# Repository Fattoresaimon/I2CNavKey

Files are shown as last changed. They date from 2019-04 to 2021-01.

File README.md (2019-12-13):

# I2C NavKey
--------------------------------------------------------------------------------
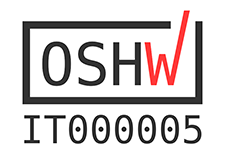
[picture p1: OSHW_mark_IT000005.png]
OSHW


## Introduction

The I2CNavKey is a small board that includes a 7 functions joypad.
The joypad has 4 directional keys plus a central button and a rotary ring. It is controllable with the I2C bus, and it's possible to configure 16 different I2C addresses.

The I2CNavKey has also 3 configurable GPIOs with the same footprint of RGB LED. This 3 GPIOs can be configured independently in 4 different way: input, output, PWM and analog input.

Since the I2CNavKey is a I2C slave, it has a series of 8 bit registers where it's possible to configure different parameters,it's also possible to detect when the buttons are pressed or when the ring is rotated.
It also has an open-drain output pin used as interrupt output. This pin is used to notify to the master when some event happens in the I2CNavKey, the source of interrupt can be customized.

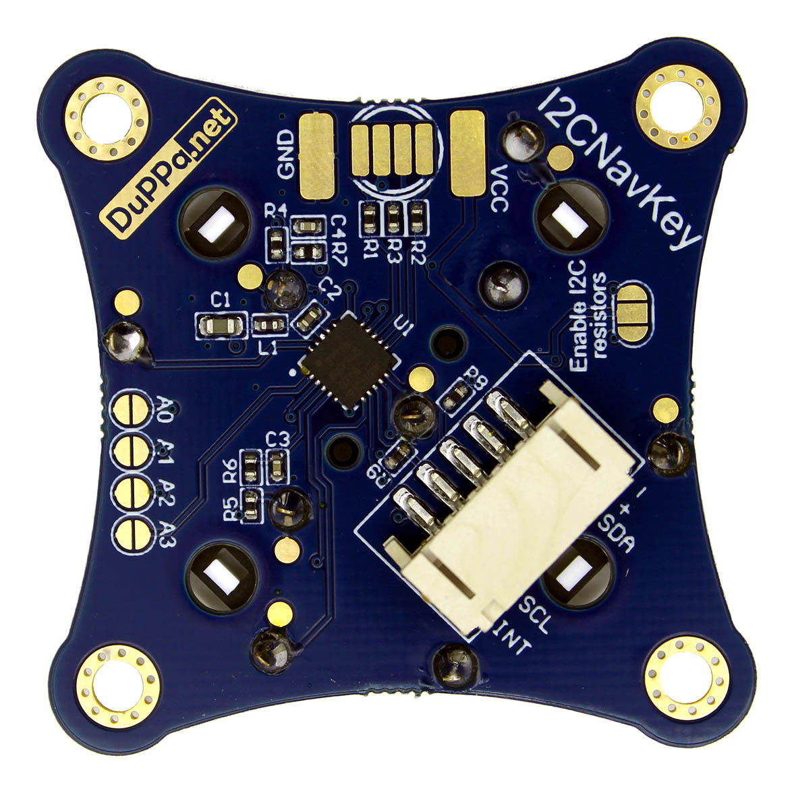
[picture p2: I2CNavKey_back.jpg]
I2CNavKey back side


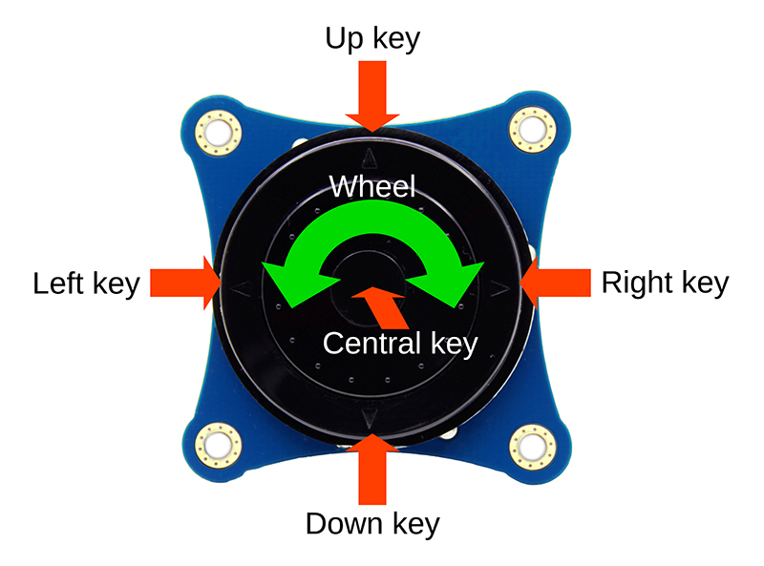
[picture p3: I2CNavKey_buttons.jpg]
I2CNavKey 7 functions


## Where you can get this board?

This project is avaiable on our [Tindie store!](https://www.tindie.com/products/16624/)

## Repository Structure
* [Arduino Library:](https://github.com/Fattoresaimon/ArduinoDuPPaLib) Repository where you can find the Arduino IDE library for the DuPPa boards
* [Raspberry Library:](/Python%20Raspberry%20Library) Ready to use library in Python for the Raspberry board with example.
* [Firmware:](/Firmware) Project folder of Microchip MPLAB X contain the code running inside of the PIC16F18345
* [Hardware:](/Hardware) Folder containing the production file, schematic, STEP file
* [Datasheet I2C NavKey:](I2CNavKey_v1.4.pdf) Datasheet of the board with the description of the registers and some useful information.

## Licensing

Hardware and firmware are licensed under GPL-3 license

Documentation is licensed under a Creative Commons BY-SA 4.0 international license

**If you want to donate for my work, i would really appreciate it. You can donate here with this link. Thank you!**



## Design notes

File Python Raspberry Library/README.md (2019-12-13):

# I2C NavKey Python library 
--------------------------------------------------------------------------------

## Introduction

Here you can find the library and some examples for Raspberry Pi.
For more details of the functionality of the board please read the [Datasheet](../I2CNavKey_v1.4.pdf) 

## Installation

The installation is very simple:

* Download the file [**i2cNavKeyLib.py** ](Source/i2cNavKeyLib.py) 
* Put the file in the folder where you have the source files.
* Import the library in your source files
``` python
import i2cNavKeyLib
```

## Initialization

The library makes available the class **i2cNavKeyLib**
For initialize the library you have to declare an instance of the class **i2cNavKeyLib** for each navkeys.
In the instance you have to declare the I2C address of the board
For example:

``` python
import smbus2
import i2cNavKeyLib

bus = smbus2.SMBus(1)
navkey = i2cNavKeyLib.i2cNavKeyLib(bus, 0x12)
```
In this example the I2C address is 0x12: jumpers A1 is soldered

## Callback Configuration

This library support the callback functionality.
There is the possibility to link a function to a specific interrupt of the I2C Encoder V2, in this way the function is automatically called when the I2C Encoder V2 generates an interrupts.

A callback function must be declared as the following:

```python
def NAME_OF_THE_FUNCTION():
```
There are 26 possible events:

| Event | Description |
|:---:|:---|
| onArrowsPush | One of the 4 direction keys is pressed |
| onArrowsRelese	| One of the 4 direction keys is released |
| onUpPush | Arrow up is pressed |
| onUpRelease | Arrow up is released |
| onDownPush | Arrow down is pressed |
| onDownRelease | Arrow down is released |
| onRightPush | Arrow right is pressed |
| onRightRelease | Arrow right is released |
| onLeftPush | Arrow left is pressed |
| onLeftRelease | Arrow left is released |
| onCentralPush | central button is pressed |
| onCentralRelease | central button is released |
| onCentralDoublePush | central button is double pushed |
| onIncrement | The counter value is incremented |
| onDecrement | The counter value is decremented |
| onChange | The counter value is incremented or decremented |
| onMax | The counter value reach the maximum threshold |
| onMin | The counter value reach the minimum threshold |
| onMinMax | The counter value reach the maximum or minimum threshold |
| onGP1Rise | GP1 configured as input, rising edge |
| onGP1Fall | GP1 configured as input, falling edge |
| onGP2Rise | GP2 configured as input, rising edge  |
| onGP2Fall | GP2 configured as input, falling edge  |
| onGP3Rise | GP3 configured as input, rising edge  |
| onGP3Fall | GP3 configured as input, falling edge  |
| onFadeProcess | Fade process terminated |

#### Examples:

```python
navkey = i2cNavKeyLib.i2cNavKeyLib(bus, 0x12)

...

 # Simple callback that ist's called when the UP button is pressed and blink the LED on GP1 #
def Up_Button():
    navkey.writeGP1(100)
    print ('Button Up Pushed!')
    navkey.writeGP1(0)

 # Simple callback that ist's called when the Down button is pressed and blink the LED on GP2 # 
def Down_Button():
    navkey.writeGP2(100)
    print ('Button Down Pushed!')
    navkey.writeGP2(0)
...

navkey.onUpPush = Up_Button # Attach the event of UP button to the callback function#
navkey.onDownPush = Down_Button # Attach the event of Down button to the callback function#

}

```

If you need to remove the link with a callback, you just need to define:
```python
navkey.onUpPush = None
```

## Methods

### Initialization
#### begin(conf)
This is used for initialize the I2CNavKey by writing the configuration register.
The parameters can be concatenate in OR mode.
Possible parameters are the following:

| Parameter | Description |
|:---:|:--- |
| INT_DATA | The Threshold, counter step and counter value are used with integer numbers |
| FLOAT_DATA | The Threshold, counter step and counter value are used with floating numbers |
| | |
| WRAP_ENABLE | Wrap enable. When the counter value reaches the CMAX+1, restart to the CMIN and vice versa |
| WRAP_DISABLE | Wrap disable. When the counter value reaches the CMAX or CMIN, the counter stops to increasing or decreasing |
| | |
| DIRE_LEFT | Rotate left side to increase the value counter |
| DIRE_RIGHT | Rotate right side to increase the value counter |
| | |
| IPUP_DISABLE | Disable the internall pull-up on the INT pin |
| IPUP_ENABLE | Enable the internall pull-up on the INT pin |
| | |
| CLK_STRECH_ENABLE | Enable the I2C clock stretch  |
| CLK_STRECH_DISABLE | Disable the I2C clock stretch  |
| | |
| EEPROM_BANK1 | Select the first EEPROM bank |
| EEPROM_BANK2 | Select the second EEPROM bank |
| | |
| RESET | Reset the board |

###### Examples:

```python
navkey.begin(i2cNavKeyLib.INT_DATA | i2cNavKeyLib.WRAP_ENABLE | i2cNavKeyLib.DIRE_RIGHT | i2cNavKeyLib.IPUP_ENABLE)
```

###  reset()
Reset of the board. 
In this command there is 8ms delay in order to make the board correctly restart.

### Configuration

#### GPx pins configuration

This 3 function are used for configure the GP pins. The parameter are the same for all of the 3 GP pins.
The interrupt configuration are used only when the pin is configured as digital input.

##### writeGP1conf(gp1)
##### writeGP2conf(gp2)
##### writeGP3conf(gp3)

| Parameter | Description |
|:---:|:---:|
|GP_PWM| Set the GP pin as PWM output|
|GP_OUT| Set the GP pin as digital output|
|GP_AN| Set the GP pin as analog input|
|GP_IN| Set the GP pin as digital input output|
|||
|GP_PULL_EN| Enable the internal pull-up of the pin|
|GP_PULL_DI| Disable the internal pull-up of the pin|
|||
|GP_INT_DI| Disable the pin interrupt|
|GP_INT_PE| Enable the interrupt at the positive edge|
|GP_INT_NE|  Enable the interrupt at the negative edge|
|GP_INT_BE|  Enable the interrupt at the positive and negative edge|

###### Examples:

```python
navkey.writeGP1conf(i2cNavKeyLib.GP_AN | i2cNavKeyLib.GP_PULL_DI | i2cNavKeyLib.GP_INT_DI)  # Configure the GP1 as analog input with the pull-up and the interrupt disable #
```

##### writeInterruptConfig(interrupt)

This method is used for enable or disable the interrupt source selectively. When an interrupt event occurs, the INT pin goes low and the event is stored in the status register.

| Parameter | Description |
|:---:|:---|
| UPR | Arrow up is released |
| UPP | Arrow up is pressed |
| DNR | Arrow down is released |
| DNP | Arrow down is pressed |
| RTR | Arrow right is released |
| RTP | Arrow right is pressed |
| LTR | Arrow left is released |
| LTP | Arrow left is pressed |
| CTRR  | Central button is released |
| CTRP  | Central button is pressed |
| CTRDP | Central button is double pushed |
| RINC  | Encoder is rotated in the increment direction  |
| RDEC  | Encoder is rotated in the decrement direction  |
| RMAX  | Maximum threshold is reached  |
| RMIN  | Minimum threshold is reached  |
| INT_2  | An event on the interrupt 2 register occurs |

###  void autoconfigInterrupt(void)

This method auto configures the **INTCONF** register according to the attached callback.
**For the proper use, must be called after the definition of the last event property.**

```python

navkey.onUpPush = Up_Button
navkey.onDownPush = Down_Button
navkey.onLeftPush = Left_Button
navkey.onRightPush = Right_Button
navkey.onCentralPush = Push_Button
navkey.onCentralDoublePush = DoublePush_Button
navkey.onChange = EncoderChange
navkey.onMax = EncoderMax
navkey.onMin = EncoderMin
  # Enable the I2C NavKey interrupts according to the previous attached callback #
navkey.autoconfigInterrupt()

```

##### writeDoublePushPeriod(dperiod)

This method is used for setting the window period **DPPERIOD** of the double push of the central button. When the value is 0, the double push option is disabled.
The I2C NavKey will multiplies this value by 10 (value x10).
###### Examples:

```python
navkey.writeDoublePushPeriod(50)  # Set a period for the double push of 500ms # 
```

##### writeFadeGP(fade)

This method is used for setting the fade speed **FADEGP** of the GP pins. It the value is 0 the fade option is disabled.

###### Examples:

```python
  navkey.writeFadeGP(5)  #GP Fade enabled with 5ms step 
```

### writeGammaGP1(gamma)
### writeGammaGP2(gamma)
### writeGammaGP3(gamma)

This method is used to set a gamma correction in case the GP pin is set to PWM

| Parameter | Description |
|:---:|:---|
| GAMMA_OFF | Gamma correction is OFF |
| GAMMA_1 | Gamma is 1, in this case the PWM is linear |
| GAMMA_1_8 | Gamma is 1.8 |
| GAMMA_2 | Gamma is 2 |
| GAMMA_2_2 | Gamma is 2.2 |
| GAMMA_2_4 | Gamma is 2.4 |
| GAMMA_2_6 | Gamma is 2.6 |
| GAMMA_2_8 | Gamma is 2.8 |

#### Examples:

```python
  navkey.writeGammaGP1(i2cNavKeyLib.GAMMA_2)
  navkey.writeGammaGP2(i2cNavKeyLib.GAMMA_2)
  navkey.writeGammaGP3(i2cNavKeyLib.GAMMA_2)
```

### Status

##### updateStatus()
Read the I2CNavKey status register **ISTATUS**. In case of events the attached callback is called.
Return value is **true** in case of some event, otherwise is **false**
In case an event of the SSTATUS  register, the SSTATUS is automatically be read.

###### Examples:

```python
  if navkey.updateStatus() == True :
  # Something happens
  
```

##### readStatus(status)

Must be called after **updateStatus()**, this method is used for checking if some event occurs on the **ISTATUS** register.
Return value is **true** in case of the event occurred, otherwise is **false**
Possible parameters are:

| Parameter | Description |
|:---:|:---|
| UPR | Arrow up is released |
| UPP | Arrow up is pressed |
| DNR | Arrow down is released |
| DNP | Arrow down is pressed |
| RTR | Arrow right is released |
| RTP | Arrow right is pressed |
| LTR | Arrow left is released |
| LTP | Arrow left is pressed |
| CTRR  | Central button is released |
| CTRP  | Central button is pressed |
| CTRDP | Central button is double pushed |
| RINC  | Encoder is rotated in the increment direction  |
| RDEC  | Encoder is rotated in the decrement direction  |
| RMAX  | Maximum threshold is reached  |
| RMIN  | Minimum threshold is reached  |
| INT_2  | An event on the interrupt 2 register occurs |

###### Example:
```python

 if  navkey.updateStatus() == True :
      if  navkey.readStatus(UPR) == True :
      	print ('Button Up Pushed!') 
      
      if  navkey.readStatus(DNR) == True :
      	print ('Button Down Pushed!') 

      if  navkey.readStatus(RTR) == True :
      	print ('Button Left Pushed!') 

      if  navkey.readStatus(LTR) == True :
      	print ('Button Right Pushed!')  

      if  navkey.readStatus(PUSHP) == True :
      	print ('Encoder pushed!')  
        
	  if  navkey.readStatus(PUSHR) == True :
      	print ('Encoder released!')   

      if  navkey.readStatus(PUSHD) == True :
      	print ('Encoder double pushed!')

```

##### readStatus()

Return the status of the register **ESTATUS**

##### readInt2(status)
Must be called after **updateStatus()**, this method is used for check if some event occurred one the secondary interrupt status **SSTATUS** register.
Return value is **true** in case of the event occurred, otherwise is **false**
Possible parameter are:

| Parameter | Description |
|:---:|:---:|
| GP1_POS  | Positive edge on the GP1 pin |
| GP1_NEG  | Negative edge on the GP1 pin |
| GP2_POS  | Positive edge on the GP2 pin |
| GP2_NEG  |Negative edge on the GP2 pin |
| GP3_POS  | Positive edge on the GP3 pin|
| GP3_NEG  |Negative edge on the GP3 pin |
| FADE_INT |Fade process finished |

###### Example:
```python
 if  navkey.updateStatus() == True :
      if  navkey.readInt2(GP1_POS)
        print("GP1 positive edge")
      
      if navkey.readInt2(GP1_NEG) == True :
        print ('GP1 negative edge ')

      if navkey.readInt2(GP2_POS)  == True :
          print('GP2 positive edge')

      if  navkey.readInt2(GP2_NEG) == True :
        print('GP2 negative edge ')

      if  navkey.readInt2(GP3_POS) == True :
        print('GP3 positive edge')

      if  navkey.readInt2(GP3_NEG) == True :
        print('GP3 negative edge ')

      if  navkey.readInt2(FADE_INT) == True :
        print('Fade process finished') 
      
```

##### readInt2Raw()

Return the status of the register **SSTATUS**

##### readFadeStatus(status)

When this function is called, it performs a I2C reading.
This function return **true** when the fade running, otherwise return **false**

| Parameter | Description |
|:---:|:---:|
| FADE_GP1  | Fade process status of the GP1 |
| FADE_GP2  | Fade process status of the GP2 |
| FADE_GP3  | Fade process status of the GP3 |

##### readFadeStatusRaw()

Return the value of the register **FSTATUS**.

### Reading methods
In this section are listed all the reading method available

##### readCounter32()
Return the counter value in the format **32bit int**, by reading all the 4 bytes of the counter value registers.

##### readCounter16()
Return the counter value in the format **16bit int**, by reading the 2 LSB  of the counter value registers.
Useful when the counter register is between the values -32768 to 32767.

##### readCounter8()
Return the counter value in the format **8bit int**, by reading the LSB byte of the counter value register.
Useful when the counter register is between the values -128 to 127

##### readCounterFloat()
Return the counter value in the format **float**, by reading all the 4 bytes of the counter value registers.
For using this function you have to configure the board with the parameter **FLOAT_DATA**.

##### readMax()
Return the maximum threshold in format **32bit int**, bye reading all the 4 bytes of the counter Max.

##### readMaxFloat()
Return the maximum threshold in format **float**, bye reading all the 4 bytes of the counter Max.

##### readMin()
Return the minimum threshold in format **32bit int**, by reading all the 4 byte of the counter Min.

##### readMinFloat()
Return the minimum  threshold in format **float**, bye reading all the 4 bytes of the counter Min.

##### readStep()
Return the minimum threshold in format **32bit int**, by reading all the 4 bytes of the ISTEP registers.

##### readStepFloat()
Return the step value in format **float**, by reading all the 4 bytes of the ISTEP registers .

##### readGP1()
Return the value of the GP1REG register. 
If the **GP1** is configured as input, it's possible to read the logic status of the pin: *1* when the pin is high, otherwise *0*.
If the **GP1** is configured as analog, it's possible to read the 8bit of the ADC.

##### readGP2()
Return the value of the GP2REG register. 
If the **GP2** is configured as input, it's possible to read the logic status of the pin: *1* when the pin is high, otherwise *0*.
If the **GP2** is configured as analog, it's possible to read the 8bit of the ADC.

##### readGP3()
Return the value of the GP3REG register. 
If the **GP3** is configured as input, it's possible to read the logic status of the pin: *1* when the pin is high, otherwise *0*.
If the **GP3** is configured as analog, it's possible to read the 8bit of the ADC. 

##### readDoublePushPeriod()
Return the value of the DPPERIOD register. 

##### readFadeGP()
Return the value of the FADEGP register. 

##### readIDCode()
Return the ID code of the I2C NavKey, that is 0x5B

##### readVersion()
Return the version of the board. 

##### readEEPROM(add)
Return the value of the EEPROM register. 
This function automatically manage the setting of the first and second memory bank.

### Writing methods

#####  writeCounter(value)
Write the counter value register with a  **32bit int** number. All of the 4 bytes are wrote.

#####  writeCounterFloat(value)
Write the counter value register with a  **float** number. All of the 4 bytes are wrote.

#####  writeMax(max)
Write the Max register with a  **32bit int** number. All of the 4 bytes are wrote.

#####  writeMax(max)
Write the Max register with a  **float** number. All of the 4 bytes are wrote.

#####  writeMin(min)
Write the Min register with a **32bit int** number. All of the 4 bytes are wrote.

#####  writeMinFloat(min)
Write the Min register with a **float** number. All of the 4 bytes are wrote.

#####  writeStep(step)
Write the increment step  with a  **32bit int** number. All of the 4 bytes are wrote.

#####  writeStepFloat(step)
Write the increment step with a  **float** number. All of the 4 bytes are wrote.

##### writeGP1(gp1)
Write the GP1REG register.
If the GP1 is configure as PWM with this method it's possible to write the PWM value.
If the GP1 is configure as output with this method it's possible to write the logic status: 1 for high, while 0 for low.

##### writeGP2(gp2)
Write the GP2REG register.
If the GP2 is configure as PWM with this method it's possible to write the PWM value.
If the GP2 is configure as output with this method it's possible to write the logic status: 1 for high, while 0 for low.

##### writeGP3(gp3)
Write the GP2REG register.
If the GP2 is configure as PWM with this method it's possible to write the PWM value.
If the GP2 is configure as output with this method it's possible to write the logic status: 1 for high, while 0 for low.

##### writeDoublePushPeriod(dperiod)
Write the DPPERIOD register.

##### writeFadeGP(fade)
Write the FADEGP register.

##### writeGammaGP1(gamma)
Configure the gamma correction for the GP1 pin

##### writeGammaGP2(gamma)
Configure the gamma correction for the GP2 pin

##### writeGammaGP3(gamma)
Configure the gamma correction for the GP3 pin

##### writeEEPROM(add, data)
Write the EEPROM memory.
The input parameter *add* is the address. This method automatically change the first or the second bank.
The input parameter *data* is the data that will be written.

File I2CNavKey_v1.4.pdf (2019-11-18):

www.duppa.net

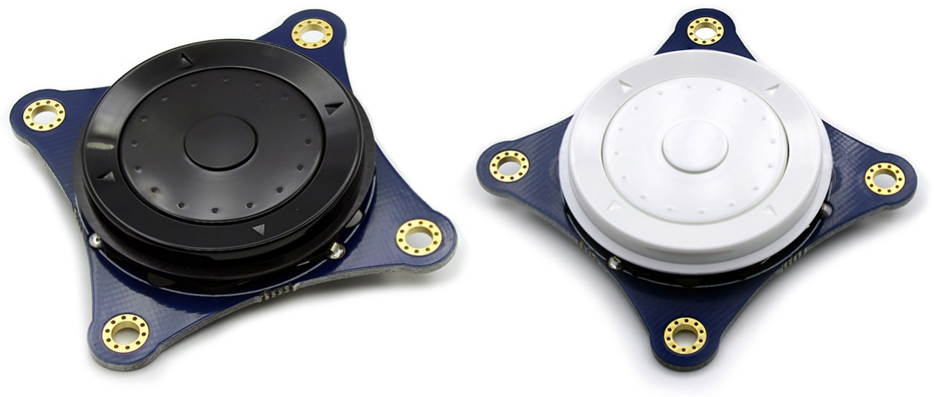
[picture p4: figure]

# I2CNavKey

## HW V1.2

November 18, 2019

Document written in LATEX

www.duppa.net | I2CNavKey

# Revision History

Revision | Date | Author(s) | Description
1.4 | 14.11.19 | Simone | Document update to the HW V1.2
1.3 | 01.08.19 | Simone | Small changes on this document layout
1.2 | 09.07.19 | Simone | Fixed the numbering of the gamma type
1.1 | 26.05.19 | Simone | Added the pull-up resistors jumpers and new photos
1.0 | 08.04.19 | Simone | First version

# Contents

1 Device Overview | 4
2 Registers | 14
3 Reference | 29
4 Issues | 30
5 Changelog | 31

6 Schematic | 32

# 1. Device Overview

The I2CNavKey is a small board that includes a 7 functions joypad.
The joypad has 4 directional keys plus a central button and a rotary ring. It is controllable with the I²C bus, and it’s possible to configure 16 different I²C addresses.

The I2CNavKey has also 3 configurable GPIOs with the same footprint of RGB LED. This 3 GPIOs can be configured independently in 4 different way: input, output, PWM and analog input.

Since the I2CNavKey is a I²C slave, it has a series of 8 bit registers where it’s possible to configure different parameters, it’s also possible to detect when the buttons are pressed or when the ring is rotated.
It also has an open-drain output pin used as interrupt output. This pin is used to notify to the master when some event happens in the I2CNavKey, the source of interrupt can be customized.

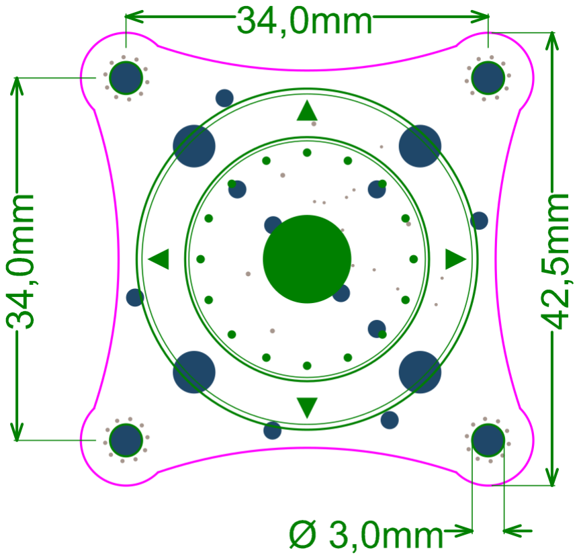
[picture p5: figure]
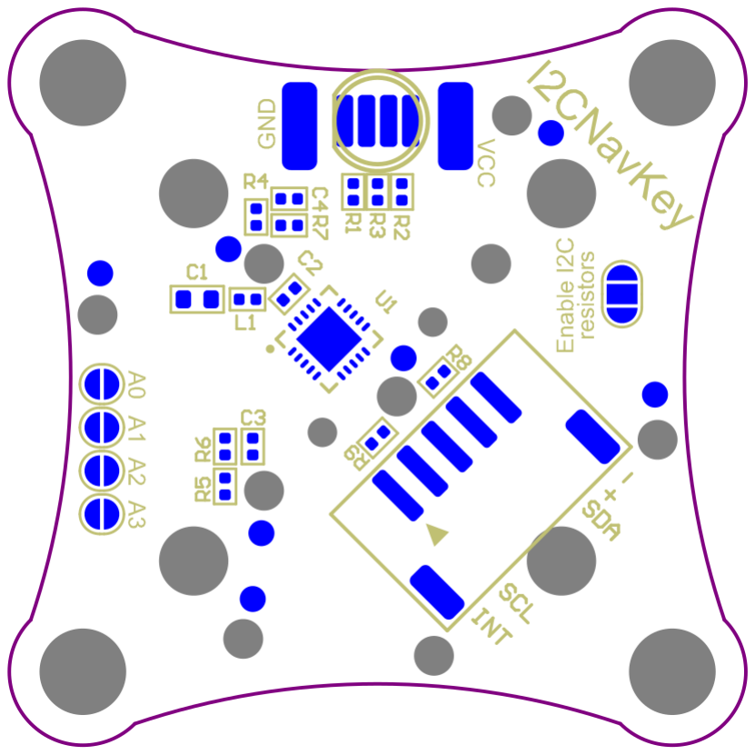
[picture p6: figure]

Figure 1.1: Dimension | Figure 1.2: Bottom view of the board

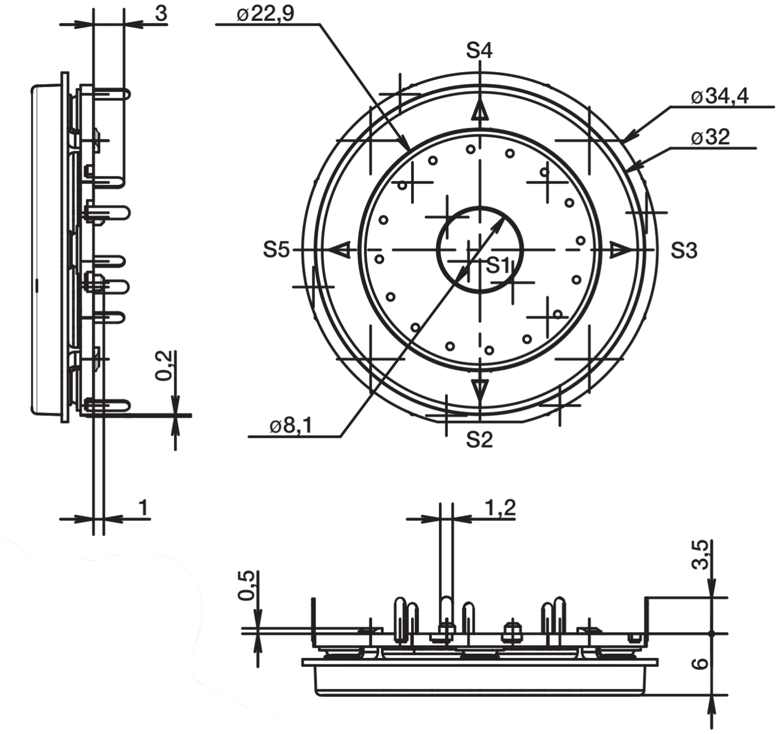
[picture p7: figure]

Figure 1.3: Dimension of the joypad: TSWB-3N-CB222 LFS from C&K

## 1.1 Electrical characteristics

Parameter | Symbol | Min | Max
Supply voltage | VDD | 3V | 5V
2C input-low level I | VIL | 0 | 0.3 * VDD
2C input-high level I | VIH | 0.8 * VDD | VDD
2C clock input frequency I | fSCL | | 400kHz
Supply current (LEDs off) | IDD | | 1.8mA
Interrupt pull-up resistor | RINT | 15kΩ | 120kΩ

## 1.2 Connection

Figure 1.2 shows the pin-out of the I2CNavKey.

Pin | I/O Type | Function
GND | Power | Ground reference for logic
Vcc | Power | Positive supply for logic
SDA | I/O | 2C data I
SCL | I | 2C clock I
INT | OD | Open-drain interrupt output

There is a 5 pin connector used to connect I2CNavKey to the master. In the HW v1.1 there is a vertical JST XH, while in the new version V1.2 there is a smaller connector JST PH mounted horizontally.

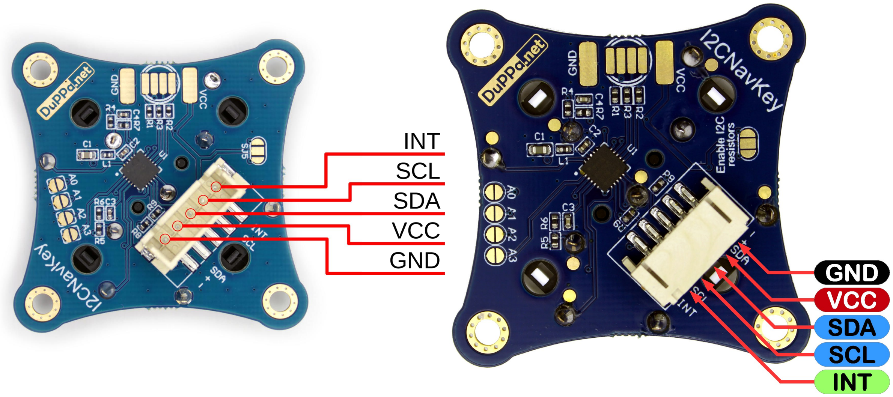
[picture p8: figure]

Figure 1.4: Pinout of the board in the previous
version HW V1.1

Figure 1.5: Pinout of the board in the HW V1.2

In order to avoid I²C address conflict with other devices on the bus, the address of each device must be different. In the section 1.3, it is described how to set the address.

## 1.3 I

## 2C interface

The I2CNavKey is a I²C slave, it’s possible to the set 16 different addresses. All of the 7-bit address can be customized by soldering the jumpers A0 - A3 on the bottom of the board. When the jumper is open, it means a logic 0. if jumper is shorted it means a logic 1.

I

2C address

7 | 6 | 5 | 4 | 3 | 2 | 1 | 0
0 | 0 | 1 | A3 | A2 | A1 | A0 | R/W

For example in the figure 1.7 the jumper A0 and A2 are shorted and the 7-bit I²C address is 21 in decimal or 0x15 in hexadecimal or 0b00010101 in binary.

The I2CNavKey has I²C pull-up resistors, by default they are not enabled. In order to enable the resistor the jumper SJ5 must be soldered.
This must be done in case that the master doesn’t have these resistors and must be enabled only one I2CNavKey in a chain. A typical value of this resistors are 4.7kΩ.
In the figure 1.7 is showed how to short the jumper SJ5.

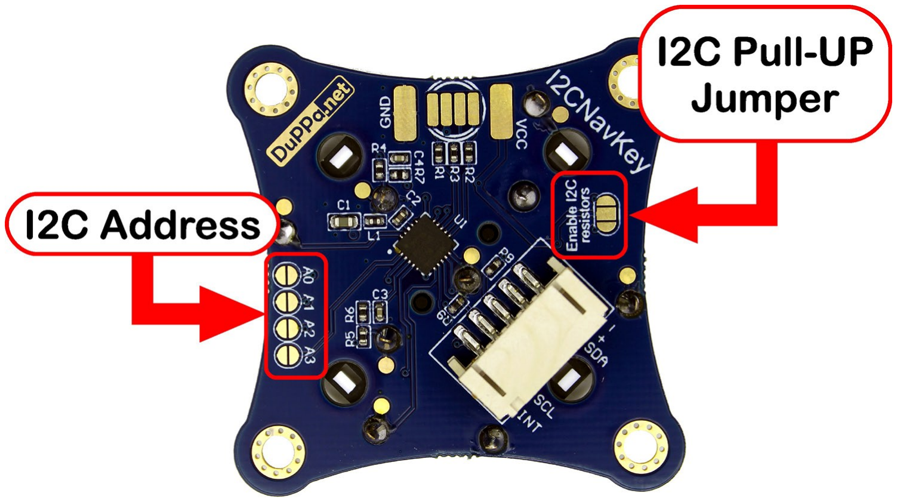
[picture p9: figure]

Figure 1.6: Jumper location of the pull-up resistor and of the address

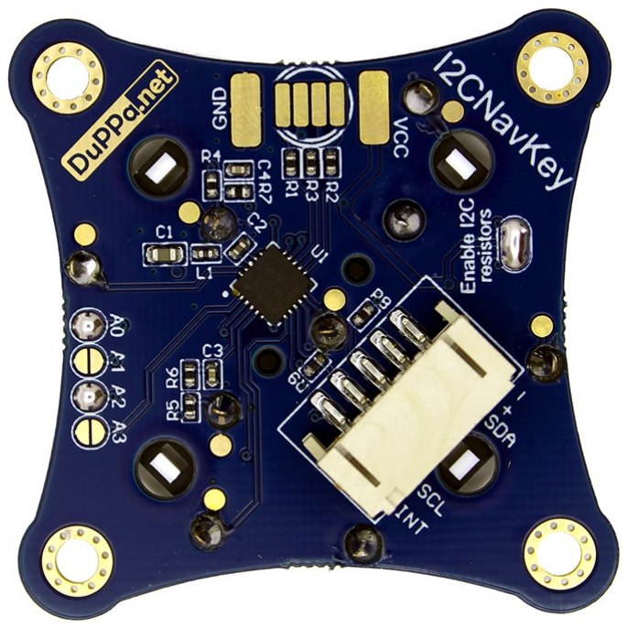
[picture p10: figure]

Figure 1.7: Example of jumper soldered: A0 and A2 shorted and also the SJ5 is shorted enabling the pull-up resistors

## 1.4 Joypad

On the I2CNavKey, there is a joypad with 7 functions:

- 4 directional buttons: up, down, left and right
- 1 central button
- Central wheel that can be rotated left and right, and it has 12 pulses per rotation.

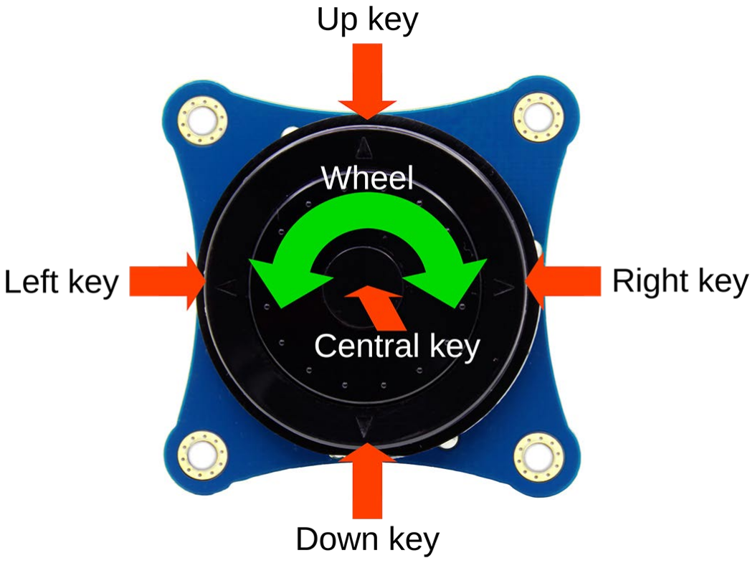
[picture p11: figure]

Figure 1.8: 7 function of the joypad

### 1.4.1 Buttons

When a button is pressed, the specific bit is set in the register ISTATUS. Every button has 2 specific bits because it’s possible to detect when the button is pressed and when is released.
The central button has also the possibility to read a fast double push by setting a window time in the register DPPERIOD. When a double push is made inside of the DPPERIOD window, the bit SCTRDP is set and it is possible to read in the ISTATUS register.
If the DPPERIOD is 0, the double push function is disabled.

### 1.4.2 Encoder

For reading the rotary encoder movement, there are 4 of 32bit registers: CVAL, CMAX, CMIN and ISTEP. All of these 4 registers can be configured to work as 32bit int or as IEEE 754 floating number, this format can be set in the GCONF register.
The counter limits are the following:
- 32bit INT: from −2147483648 to +2147483647
- IEEE 754 float: from −126.0 to +127.0

In case of 32bit int, it is not necessary to read all the 4 bytes, you can read only the first 8 bit or the first 16 bit. For example, if you want to count between 0 and 10, you can read only the first byte of the CVAL register. In this way, you can save I2C transactions.
Every time the encoder moves one step, the value of the CVAL register is increased or decreased of the value of ISTEP. The direction of the rotation decides if ISTEP is added or subtracted from CVAL.
CMAX and CMIN are used for setting a minimum and maximum thresholds of CVAL. In the GCONF register, there is WRAPE bit. This bit is used to enable or disable a wrap functionality of CVAL when it exceeds from the thresholds.
For example, if i configure the I2CNavKey as following:
- CVAL= 0
- CMAX = 5
- CMIN = -5
- ISTEP= 1

I will have CVAL is incremented of 1 at each rotation step of the encoder. The maximum value that CVAL can reach will be 5 while the minimum is -5. In the figure 1.9 shows the value of CVAL.

As showed in the figure 1.10, when WRAPE is set to 1 when CVAL reaches the value of 5, at the next increment CVAL it will be wrapped to -5.
Every time when the encoder is rotated one step and when CVAL reaches the thresholds, an interrupt is generated and it is possible to read in the register ISTATUS.

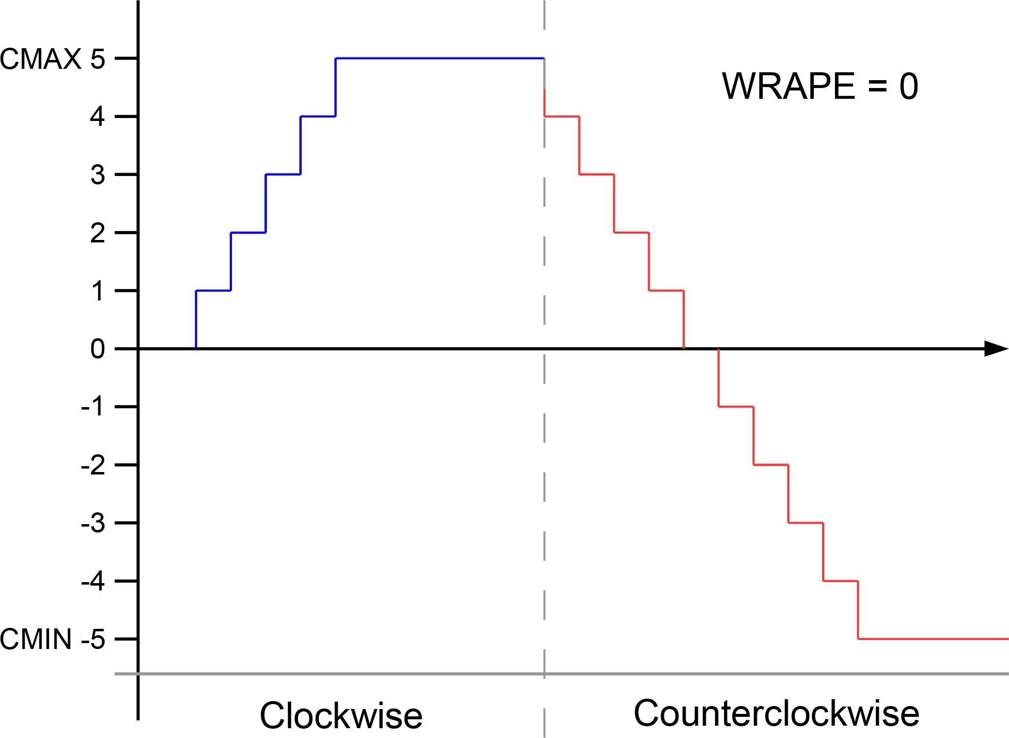
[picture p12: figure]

Figure 1.9: Blue and red lines are the CVAL values when the encoder is rotated and the WRAPE is disabled

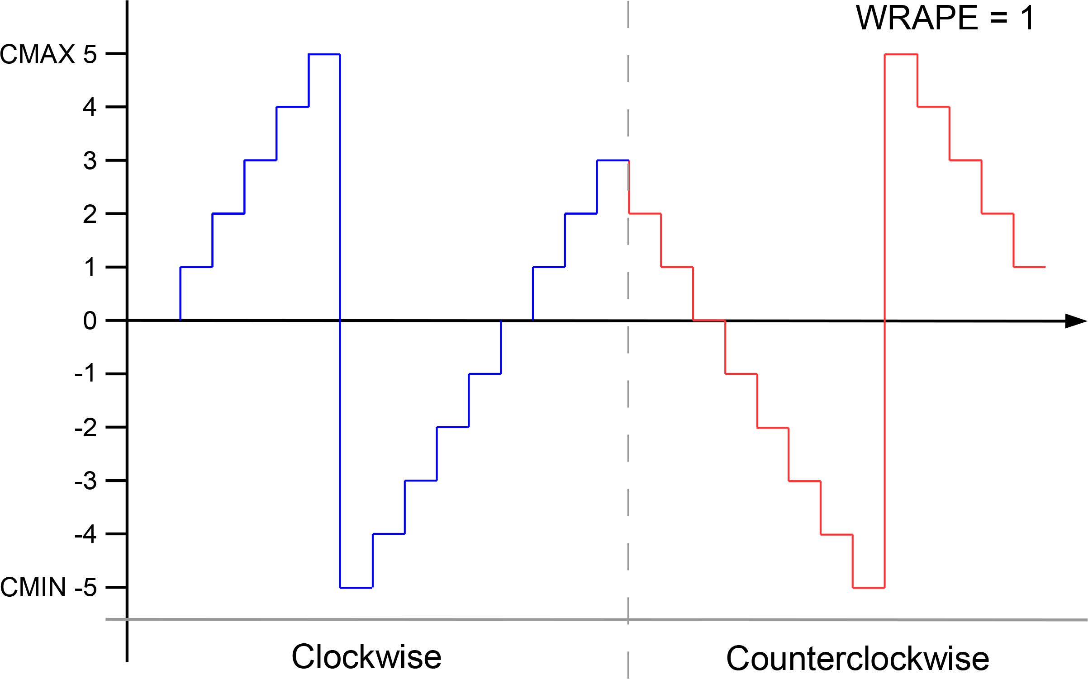
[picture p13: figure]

Figure 1.10: Blue and red line are the CVAL values when the encoder is rotate and the WRAPE is enabled

## 1.5 GP pins

There are 3 configurable GP pins, they are called GP1, GP2 and GP3. They have the same footprint of an 5mm RGB led. In figure 1.11, it is shown the position. Each pin can be configured to be:

- PWM: The pins is configured to be a PWM output.
- Analog input: The pins is configured to be an input of the internal ADC.
- GPIO output: The pins is configured to be a digital output.
- GPIO Input: The pin is configured to be a digital input.

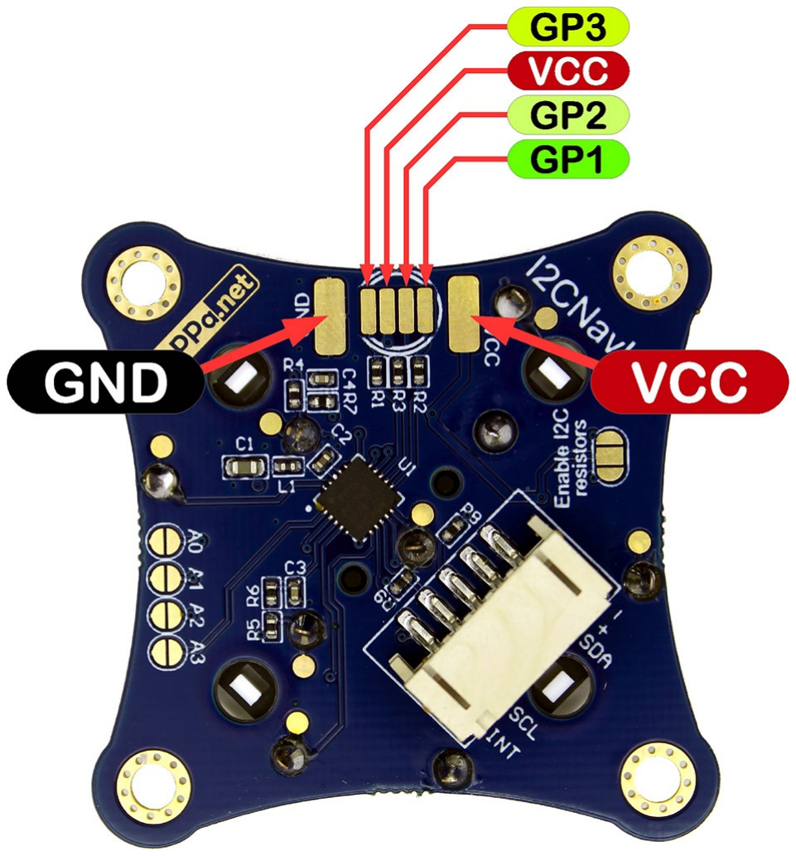
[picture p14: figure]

Figure 1.11: GP pins pinout

### 1.5.1 PWM mode

A GP pins can be configured in PWM mode by configuring the GPxMODE 1
to 0x00. The default configuration of the GP pins at the start up is PWM. Once the GP pin is configure in PWM mode, it is possible to set the PWM value by writing the corresponding GPxREG.
The PWM is resolution 10bit with a frequency of 31.25kHz, but the user can not access to the full resolution. It is possible to set a PWM value between 0% to 100% by writing 0 to 100 to the GPxREG.
The PWM is inverted, this means that when the PWM is 0% the GP pin voltage is VCC while when it is 100% the GP pin is GND.
In this way it is possible to connect a common anode RGB LED and have the LED off when the PWM is 0 and full on when the PWM is 100.
To each PWM outputs it is possible to configure a specific gamma correction by writing the register GAMMAGPx. There are 7 type of gamma correction:

✥ Gamma 1 (linear)

✥ Gamma 1.8

✥ Gamma 2.0

✥ Gamma 2.2

✥ Gamma 2.4

✥ Gamma 2.6

✥ Gamma 2.8

In the figure 1.12 is showed the relationship between the PWM at the full resolution and the PWM settable from the user.

1
In a register name the x correspond to 1, 2 or 3

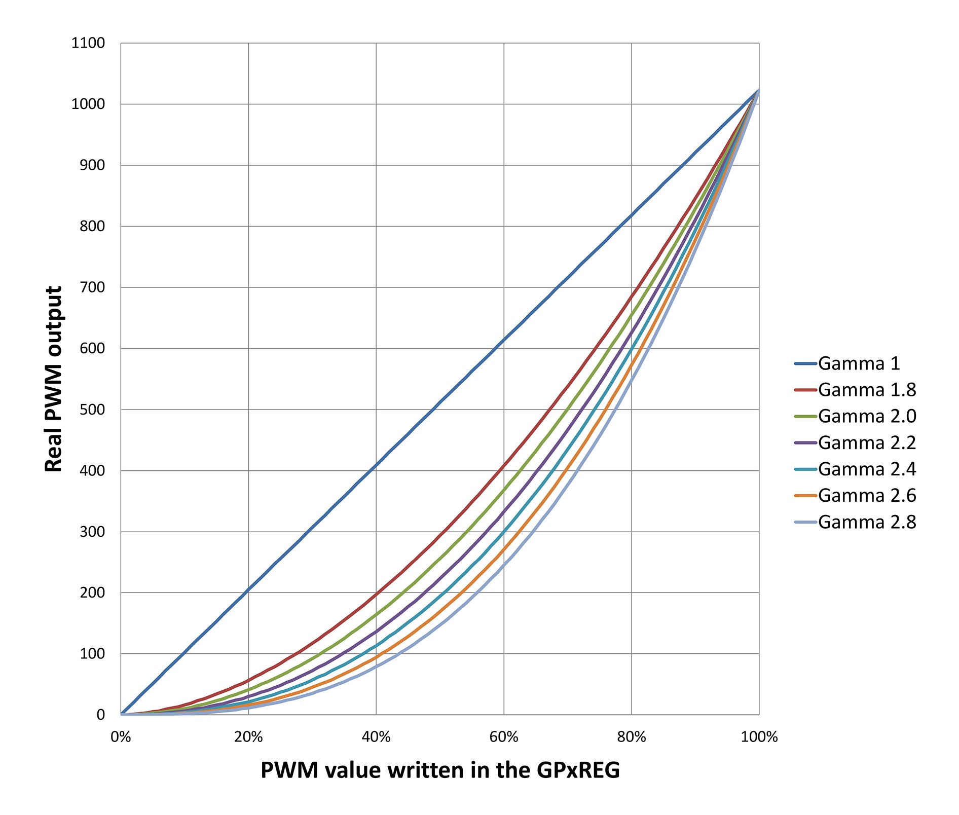
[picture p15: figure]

Figure 1.12: Possible gamma option

Fade function

The I2CNavKey has an auto fading features.
There is the register FADEGP, the value you write inside these registers is the step speed of the fading ramp, and it’s in ms. The fading will follow the selected gamma correction. If the value is 0, the fade feature is disabled. It means that when the new value of PWM is written, it is immediately updated to the output.
The fading process starts when a PWM value is written. Fading process is complete according to the PWM value you have set. When the internal fade PWM value is the same of the PWM value (it means that when fading is complete), an interrupt will be generated. Let’s make an example:

At the startup, i write as:

- GP1REG = 0
- GP2REG = 0
- GP3REG = 0
- FADEGP = 1

In above case, the LEDs of the encoder are off and the fade has 1ms step size.
Now i write as: GP1REG=100.
This moment, the ramp of the GP1REG starts and reaches the value 0x100 in 100ms. (the other LEDs remain OFF) When the ramp reaches 100, i get an interrupt from the INT pin.
After this, i write as: GP1REG=0x00. At this point, the fade ramp starts again and it will turn off the LED in 100ms, and an interrupt will be generated at the end.
The figure 1.13 is showing an example of the fade output when a PWM value is written in different moments, as well as when the interrupt of the fade is generated.

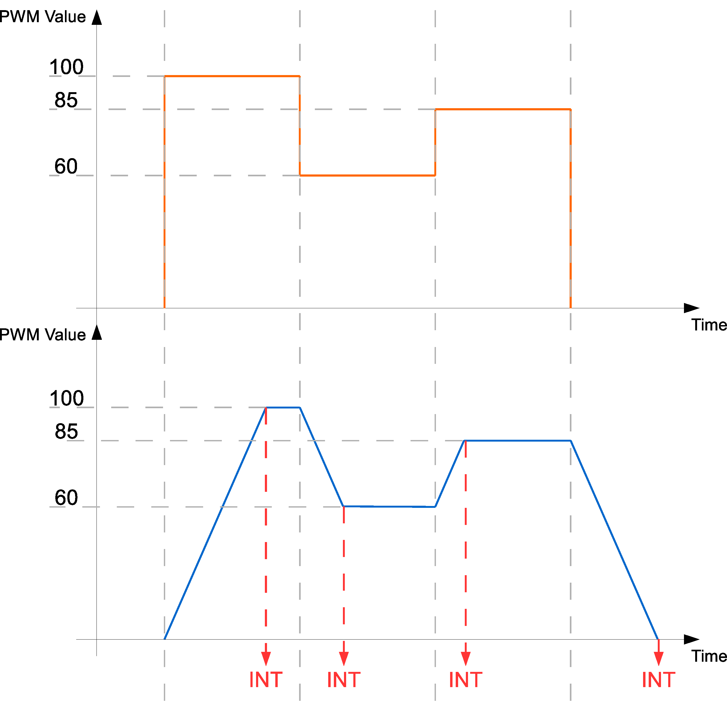
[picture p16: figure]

Figure 1.13: Time diagram of the fade output when writing on the PWM register

### 1.5.2 OUT mode

A GP pin can be configured as output mode by configuring the GPxMODE to 0x01. When the pin is configured as output writing 1 to GPxREG it make the GP pin high, while writing 0 make the pin low.

### 1.5.3 ADC mode

A GP pin can be configured as ADC mode by configuring the GPxMODE to 0x02. It is possible to read the ADC value by reading the register GPxREG. The content of the register updates every 10ms. When the GP pin is tied to 0 the ADC value is 0, while when the GP pin is tied to VCC the ADC value is 255. In this case it is also possible to enable the internal pull-up by writing 1 in the GPxPUL field.

### 1.5.4 IN mode

A GP pin can be configured as input mode by configuring the GPxMODE to 0x03. In this case, it is also possible to enable the internal pull-up by writing 1 in the GPxPUL field. It is also possible to configure the GP pin to generate an interrupt when the signal change. In the field GPxINT it possible to enable the interrupt when there is a positive edge, negative edge or both. The interrupt can be read in the register I2STATUS.It can be also reported to the INT pin by enabling the SINT2L bit.

## 1.6 EEPROM

The I2CNavKey has 256 bytes of EEPROM.
This memory is divided in two banks of 128 bytes. With the bit MBANK in the GCONF register, it is possible to choose either the bank 1 or the bank 2.
The memory area is between 0x80 and 0xFF address. To use the EEPROM, user only needs to perform reading or a writing in these address areas.
The writing time takes 4 - 5ms to be executed. Wait this time before sending other commands.

## 1.7 Interrupt

The I2CNavKey has multiple interrupt source previously described. When an interrupt is generated, the INT pin is tied low. By reading the register ISTATUS, the interrupts are cleared and the INT pin returns high.

The INT pin is open-drain output. Hence it requires an external pull-up resistor, or internal pull-up resistor can be enabled by setting the bit IPUD to 1.
In a chain of I2CNavKey all the INT pins can be connected together, like the pin of the I²C. When an interrupt occurs, user has to scan the boards in the chain to find who generates the interrupt.
With the register INTCONF, it is possible to enable or disable interrupt. When an interrupt is disabled, the corresponding bit is set, but the INT pin is not affected.

# 2. Registers

In this section, the internal registers of I2CNavKey is described.
The I2CNavKey has the auto increment feature. This means that after writing or reading a register, the internal address pointer is automatically incremented by one.
Address range | Name | Description | Dimension | Default value
0x00 | GCONF | General Configuration | 1 Byte | 0
0x01 | GP1CONF | GP 1 Configuration | 1 Byte | 0
0x02 | GP2CONF | GP 2 Configuration | 1 Byte | 0
0x03 | GP3CONF | GP 3 Configuration | 1 Byte | 0
0x04 0x05 | INTCONF | INT pin Configuration | 2 Byte | 0
0x06 - 0x07 | ISTATUS | Interrupt Status | 2 Byte | 0
0x08 | I2STATUS | Secondary interrupt status | 1 Byte | 0
0x09 | FSTATUS | Fade process status | 1 Byte | 0
0x0A - 0x0D | CVAL | Counter Value | 4 Byte | 0
0x0E - 0x11 | CMAX | Counter Max value | 4 Byte | 0
0x12 - 0x15 | CMIN | Counter Min value | 4 Byte | 0
0x16 - 0x19 | ISTEP | Increment step value | 4 Byte | 1
0x1A | GP1REG | I/O GP1 register | 1 Byte | 0
0x1B | GP2REG | I/O GP2 register | 1 Byte | 0
0x1C | GP3REG | I/O GP3 register | 1 Byte | 0
0x1D | DPPERIOD | Double push period | 1 Byte | 0
0x1E | FADEGP | Fade timer step of GPs ports | 1 Byte | 0
0x1F | GAMMAGP1 | Gamma correction on PWM of GP1 | 1 Byte | 0
0x20 | GAMMAGP2 | Gamma correction on PWM of GP2 | 1 Byte | 0
0x21 | GAMMAGP3 | Gamma correction on PWM of GP3 | 1 Byte | 0
0x70 | IDCODE | I2CNavKey unique code | 1 Byte | 0x5B
0x71 | VERSION | I2CNavKey version | 1 Byte | 0x12
0x80 - 0xFF | EEPROM | EEPROM memory | 128 Byte | 0

## 2.1 Configuration

### 2.1.1 General Configuration

GCONF Address: 0x00
7 | 6 | 5 | 4 | 3 | 2 | 1 | 0
R/W-0 | R/W-0 | R/W-0 | R/W-0 | R/W-0 | R/W-0 | R/W-0 | R/W-0
RESET | | MBANK | CKSRC | IPUD | DIRE | WRAPE | DTYPE

❖ DTYPE Data type of the register: CVAL, CMAX, CMIN and ISTEP.

1: The registers are considered float numbers IEEE 754

0: The registers are considered int 32bit

❖ WRAPE Enable counter wrap.

1: Wrap enable. When the counter value reaches the CMAX+1, restart to the CMIN and vice versa

0: Wrap disable. When the counter value reaches the CMAX or CMIN, the counter stops to increasing or decreasing

❖ DIRE Direction of the encoder when increment.

1: Rotate left side to increase the counter value

0: Rotate right side to increase the counter value

❖ IPUD Interrupt Pull-UP disable.

1: Disable

0: Enable

❖ CKSRC Enable or disable I²C clock stretch

1: Enabled

0: Disabled

❖ MBANK Select the EEPROM memory bank. Each bank are 128 byte wide

1: Second memory bank

0: First memory bank

❖ RST Reset of the I2CNavKey

1: Reset of the I2CNavKey. The RESET command takes 400us to be executed.

0: No reset

### 2.1.2 GP1 Configuration

GP1CONF Address: 0x01
7 | 6 | 5 | 4 | 3 | 2 | 1 | 0
R/W-0 | R/W-0 | R/W-0 | R/W-0 | R/W-0 | R/W-0 | R/W-0 | R/W-0
- | - | - | GP1INT | | GP1PUL | GP1MODE

❖ GP1MODE Configuration of the pin GP1

00: PWM output
01: GPIO output Push-Pull

10: Analog input
11: GPIO Input

❖ GP1PUL Enable or disable the internal pull-up.

0: Pull-UP disable

1: Pull-UP enabled

❖ GP1INT Configuration of the interrupt, available only when the pin is configured as input

00: Interrupt disabled

01: Interrupt on positive edge

10: Interrupt on negative edge

11: Interrupt on both edges

### 2.1.3 GP2 Configuration

GP2CONF Address: 0x02
7 | 6 | 5 | 4 | 3 | 2 | 1 | 0
R/W-0 | R/W-0 | R/W-0 | R/W-0 | R/W-0 | R/W-0 | R/W-0 | R/W-0
- | - | - | GP2INT | | GP2PUL | GP2MODE

❖ GP2MODE Configuration of the pin GP2

00: PWM output
01: GPIO output Push-Pull

10: Analog input
11: GPIO Input

❖ GP2PUL Enable or disable the internal pull-up.

0: Pull-UP disable

1: Pull-UP enabled

❖ GP2INT Configuration of the interrupt, available only when the pin is configured as input

00: Interrupt disabled

01: Interrupt on positive edge

10: Interrupt on negative edge

11: Interrupt on both edges

### 2.1.4 GP3 Configuration

GP3CONF Address: 0x03
7 | 6 | 5 | 4 | 3 | 2 | 1 | 0
R/W-0 | R/W-0 | R/W-0 | R/W-0 | R/W-0 | R/W-0 | R/W-0 | R/W-0
- | - | - | GP3INT | | GP3PUL | GP3MODE

❖ GP3MODE Configuration of the pin GP3

00: PWM output
01: GPIO output Push-Pull

10: Analog input
11: GPIO Input

❖ GP3PUL Enable or disable the internal pull-up.

0: Pull-UP disable

1: Pull-UP enabled

❖ GP3INT Configuration of the interrupt, available only when the pin is configured as input

00: Interrupt disabled

01: Interrupt on positive edge

10: Interrupt on negative edge

11: Interrupt on both edges

## 2.2 Interrupt output Configuration

This register is used to enable or disable the interrupt source selectively. When an interrupt event occurs, the INT pin goes low and the event is stored in the status register.

INTCONF Address: 0x04
15 | 14 | 13 | 12 | 11 | 10 | 9 | 8
R/W-0 | R/W-0 | R/W-0 | R/W-0 | R/W-0 | R/W-0 | R/W-0 | R/W-0
INT2 | IRMIN | IRMAX | IRDEC | IRINC | ICTRDP | ICTRP | ICTRR
Address: 0x05
7 | 6 | 5 | 4 | 3 | 2 | 1 | 0
R/W-0 | R/W-0 | R/W-0 | R/W-0 | R/W-0 | R/W-0 | R/W-0 | R/W-0
ILTP | ILTR | IRTP | IRTR | IDNP | IDNR | IUPP | IUPR

❖ IUPR Button UP release bit

1: Interrupt enabled when the UP button is released.

0: Interrupt disabled

❖ IUPP Button UP press bit

1: Interrupt enabled when the UP button is pressed.

0: Interrupt disabled

❖ IDNR Button DOWN release bit

1: Interrupt enabled when the DOWN button is released.

0: Interrupt disabled

❖ IDNP Button DOWN press bit

1: Interrupt enabled when the DOWN button is pressed.

0: Interrupt disabled

❖ IRTR Button RIGHT release bit

1: Interrupt enabled when the RIGHT button is released.

0: Interrupt disabled

❖ IRTP Button RIGHT press bit

1: Interrupt enabled when the RIGHT button is pressed.

0: Interrupt disabled

❖ ILTR Button LEFT release bit

1: Interrupt enabled when the LEFT button is released.

0: Interrupt disabled

❖ ILTP Button LEFT press bit

1: Interrupt enabled when the LEFT button is pressed.

0: Interrupt disabled

❖ ICTRR CENTRAL button release bit

1: Interrupt enabled when the CENTRAL button is released.

0: Interrupt disabled

❖ ICTRP Push button press bit

1: Interrupt enabled when the CENTRAL button is pressed.

0: Interrupt disabled

❖ ICTRDP CENTRAL button double press

1: Interrupt enabled when the CENTRAL button is double pressed.

0: Interrupt disabled

❖ IRINC Rotary encoder direction of increase

1: Interrupt enabled when the encoder is rotated in the direction of increase

0: Interrupt disabled

❖ IRDEC Rotary encoder direction of decrease

1: Interrupt enabled when the encoder is rotated in the direction of decrease

0: Interrupt disabled

❖ IRMAX CVAL reaches CMAX bit

1: Interrupt enabled when CVAL reaches CMAX

0: Interrupt disabled

❖ IRMIN CVAL reaches CMIN bit

1: Interrupt enabled when CVAL reaches CMIN

0: Interrupt disabled

❖ INT2 Enable the secondary interrupts

1: Secondary interrupt enabled

0: Secondary interrupt disabled

## 2.3 Status

### 2.3.1 I2CNavKey Status

This register is only readable, when is read is automatically cleared.

ISTATUS Address: 0x06
15 | 14 | 13 | 12 | 11 | 10 | 9 | 8
R/W-0 | R/W-0 | R/W-0 | R/W-0 | R/W-0 | R/W-0 | R/W-0 | R/W-0
SINT2 | SRMIN | SRMAX | SRDEC | SRINC | SCTRDP | SCTRP | SCTRR
Address: 0x07
7 | 6 | 5 | 4 | 3 | 2 | 1 | 0
R/W-0 | R/W-0 | R/W-0 | R/W-0 | R/W-0 | R/W-0 | R/W-0 | R/W-0
SLTP | SLTR | SRTP | SRTR | SDNP | SDNR | SUPP | SUPR

❑ SUPR Button UP release bit

1: UP button is released

0: UP button is not released

❑ SUPP Button UP press bit

1: UP button is pressed

0: UP button is not pressed

❑ SDNR Button DOWN release bit

1: DOWN button is released

0: DOWN button is not released

❑ SDNP Button DOWN press bit

1: DOWN button is pressed

0: DOWN button is not pressed

❑ SRTR Button RIGHT release bit

1: RIGHT button is released

0: RIGHT button is not released

❑ SRTP Button RIGHT press bit

1: RIGHT button is pressed

0: RIGHT button is not pressed

❑ SLTR Button LEFT release bit

1: LEFT button is released

0: LEFT button is not released

❑ SLTP Button LEFT press bit

1: LEFT button is pressed

0: LEFT button is not released

❑ SCTRR CENTRAL button release bit

1: CENTRAL button is released

0: CENTRAL button is not released

❑ SCTRP CENTRAL button press bit

1: CENTRAL button is pressed

0: CENTRAL button is not pressed

❑ SCTRDP CENTRAL button double press

1: CENTRAL button is double pressed

0: CENTRAL button is not double pressed

❑ RINC Rotary encoder is rotated in the increase direction

1: Encoder is rotated

0: Encoder is not rotated

❑ RDEC Rotary encoder is rotated in the decrease direction

1: Encoder is rotated

0: Encoder is not rotated

❑ RMAX Status of the counter value

1: CVAL reaches the CMAX value

0: CVAL is below the CMAX value

❑ RMIN Status of the counter value

1: CVAL reaches the CMIN value

0: CVAL is above the CMIN value

❑ SINT2 Secondary interrupt status

1: Secondary interrupt event occurs

0: No secondary event occurs

### 2.3.2 Secondary interrupt status

In this register is possible to check the event of the fade process as well as the GP pins when is configured as input. This register if only readable, when is read is automatically cleared.

I2STATUS Address: 0x08
7 | 6 | 5 | 4 | 3 | 2 | 1 | 0
R-0 | R-0 | R-0 | R-0 | R-0 | R-0 | R-0 | R-0
- | FADE | EGP3 | | EGP2 | | EGP1

❑ GP1 Interrupt on the GP1 port.

00: No event occurs

01: Positive edge event

10: Negative edge event

❑ GP2 Interrupt on the GP2 port.

00: No event occurs

01: Positive edge event

10: Negative edge event

❑ GP3 Interrupt on the GP3 port.

00: No event occurs

01: Positive edge event

10: Negative edge event

❑ FADE Fade process interrupt.

1: Fade process event

0: No event in the fade process

### 2.3.3 Fade process status

With this register is possible to check the status of the PWM channel during the fade process. This register is only readable and the bits are set or cleared automatically during the fade process.

FSTATUS Address: 0x09
7 | 6 | 5 | 4 | 3 | 2 | 1 | 0
R-0 | R-0 | R-0 | R-0 | R-0 | R-0 | R-0 | R-0
- | - | - | - | - | FGP3 | FGP2 | FGP1

❑ FGP1 Fade status process of the GP1

1: Fade process is running

0: Fade process terminated

❑ FGP2 Fade status process of the GP2

1: Fade process is running

0: Fade process terminated

❑ FGP3 Fade status process of the GP3

1: Fade process is running

0: Fade process terminated

## 2.4 Encoder registers

These 4 registers are in 32bit format. It is possible to read/write a single byte independently, no need to read/write all the 4 bytes at time.
They can be also used in float mode IEEE 754, but the DTYPE bit must be set.

### 2.4.1 Counter Value

CVAL Address: 0x0A
31 | 30 | 29 | 28 | 27 | 26 | 25 | 24
R/W-0 | R/W-0 | R/W-0 | R/W-0 | R/W-0 | R/W-0 | R/W-0 | R/W-0
CVAL BYTE 4 <31 - 24>
Address: 0x0B
23 | 22 | 21 | 20 | 19 | 18 | 17 | 16
R/W-0 | R/W-0 | R/W-0 | R/W-0 | R/W-0 | R/W-0 | R/W-0 | R/W-0
CVAL BYTE 3 <23 - 16>
Address: 0x0C
15 | 14 | 13 | 12 | 11 | 10 | 9 | 8
R/W-0 | R/W-0 | R/W-0 | R/W-0 | R/W-0 | R/W-0 | R/W-0 | R/W-0
CVAL BYTE 2 <15 - 8>
Address: 0x0D
7 | 6 | 5 | 4 | 3 | 2 | 1 | 0
R/W-0 | R/W-0 | R/W-0 | R/W-0 | R/W-0 | R/W-0 | R/W-0 | R/W-0
CVAL BYTE 1 <7 - 0>

### 2.4.2 Counter Max

CMAX Address: 0x0E
31 | 30 | 29 | 28 | 27 | 26 | 25 | 24
R/W-0 | R/W-0 | R/W-0 | R/W-0 | R/W-0 | R/W-0 | R/W-0 | R/W-0
CMAX BYTE 4 <31 - 24>
Address: 0x0F
23 | 22 | 21 | 20 | 19 | 18 | 17 | 16
R/W-0 | R/W-0 | R/W-0 | R/W-0 | R/W-0 | R/W-0 | R/W-0 | R/W-0
CMAX BYTE 3 <23 - 16>
Address: 0x10
15 | 14 | 13 | 12 | 11 | 10 | 9 | 8
R/W-0 | R/W-0 | R/W-0 | R/W-0 | R/W-0 | R/W-0 | R/W-0 | R/W-0
CMAX BYTE 2 <15 - 8>
Address: 0x11
7 | 6 | 5 | 4 | 3 | 2 | 1 | 0
R/W-0 | R/W-0 | R/W-0 | R/W-0 | R/W-0 | R/W-0 | R/W-0 | R/W-0
CMAX BYTE 1 <7 - 0>

### 2.4.3 Counter Min

CMIN Address: 0x12
31 | 30 | 29 | 28 | 27 | 26 | 25 | 24
R/W-0 | R/W-0 | R/W-0 | R/W-0 | R/W-0 | R/W-0 | R/W-0 | R/W-0
CMIN BYTE 4 <15 - 8>
Address: 0x13
23 | 22 | 21 | 20 | 19 | 18 | 17 | 16
R/W-0 | R/W-0 | R/W-0 | R/W-0 | R/W-0 | R/W-0 | R/W-0 | R/W-0
CMIN BYTE 3 <7 - 0>
Address: 0x14
15 | 14 | 13 | 12 | 11 | 10 | 9 | 8
R/W-0 | R/W-0 | R/W-0 | R/W-0 | R/W-0 | R/W-0 | R/W-0 | R/W-0
CMIN BYTE 2 <15 - 8>
Address: 0x15
7 | 6 | 5 | 4 | 3 | 2 | 1 | 0
R/W-0 | R/W-0 | R/W-0 | R/W-0 | R/W-0 | R/W-0 | R/W-0 | R/W-0
CMIN BYTE 1 <7 - 0>

### 2.4.4 Increment step

ISTEP Address: 0x16
31 | 30 | 29 | 28 | 27 | 26 | 25 | 24
R/W-0 | R/W-0 | R/W-0 | R/W-0 | R/W-0 | R/W-0 | R/W-0 | R/W-0
ISTEP BYTE 4 <15 - 8>
Address: 0x17
23 | 22 | 21 | 20 | 19 | 18 | 17 | 16
R/W-0 | R/W-0 | R/W-0 | R/W-0 | R/W-0 | R/W-0 | R/W-0 | R/W-0
ISTEP BYTE 3 <7 - 0>
Address: 0x18
15 | 14 | 13 | 12 | 11 | 10 | 9 | 8
R/W-0 | R/W-0 | R/W-0 | R/W-0 | R/W-0 | R/W-0 | R/W-0 | R/W-0
ISTEP BYTE 2 <15 - 8>
Address: 0x19
7 | 6 | 5 | 4 | 3 | 2 | 1 | 0
R/W-0 | R/W-0 | R/W-0 | R/W-0 | R/W-0 | R/W-0 | R/W-0 | R/W-0
ISTEP BYTE 1 <7 - 0>

## 2.5 GPs registers

The usage of these register depends of the configuration of the GP pins:

- PWM Is possible to write the PWM value: 0 to 100.
- GPIO output: Is possible to write 1 or 0 for setting the output logic level.
- Analog input: Is possible to read the ADC value: 8 bit format.
- GPIO Input: Is possible to read the logic level of the output.

### 2.5.1 GP1 register

GP1REG Address: 0x1A
7 | 6 | 5 | 4 | 3 | 2 | 1 | 0
R/W-0 | R/W-0 | R/W-0 | R/W-0 | R/W-0 | R/W-0 | R/W-0 | R/W-0
GP1 Value <7 - 0>

### 2.5.2 GP2 register

GP2REG Address: 0x1B
7 | 6 | 5 | 4 | 3 | 2 | 1 | 0
R/W-0 | R/W-0 | R/W-0 | R/W-0 | R/W-0 | R/W-0 | R/W-0 | R/W-0
GP2 Value <7 - 0>

### 2.5.3 GP3 register

GP3REG Address: 0x1C
7 | 6 | 5 | 4 | 3 | 2 | 1 | 0
R/W-0 | R/W-0 | R/W-0 | R/W-0 | R/W-0 | R/W-0 | R/W-0 | R/W-0
GP3 Value <7 - 0>

## 2.6 Timing registers

This register are used for changing some timing parameter

### 2.6.1 Double push time

This register is used for setting the interval for the detection of the double push of the central button. The value is in ms × 10. When this register is 0 this function is disabled.

DPPERIOD Address: 0x1D
7 | 6 | 5 | 4 | 3 | 2 | 1 | 0
R/W-0 | R/W-0 | R/W-0 | R/W-0 | R/W-0 | R/W-0 | R/W-0 | R/W-0
PDPUSH <7 - 0>

### 2.6.2 Fade GP ports

This register is used for setting the fade speed of the GP ports. The value is in ms and indicate the time of one step. This register is working only if the GP port are configured in PWM

FADEGP Address: 0x1E
7 | 6 | 5 | 4 | 3 | 2 | 1 | 0
R/W-0 | R/W-0 | R/W-0 | R/W-0 | R/W-0 | R/W-0 | R/W-0 | R/W-0
FADEGP <7 - 0>

## 2.7 Gamma correction

This register is used for applying a gamma correction in case the GP port is used as PWM. It can be very useful when a LED is connected.

GAMMAGP1 Address: 0x1F
7 | 6 | 5 | 4 | 3 | 2 | 1 | 0
- | - | - | - | - | R/W-0 | R/W-0 | R/W-0
| | | | | GAMMAGP1 <2 - 0>

GAMMAGP2 Address: 0x20
7 | 6 | 5 | 4 | 3 | 2 | 1 | 0
- | - | - | - | - | R/W-0 | R/W-0 | R/W-0
| | | | | GAMMAGP2 <2 - 0>

GAMMAGP3 Address: 0x21
7 | 6 | 5 | 4 | 3 | 2 | 1 | 0
- | - | - | - | - | R/W-0 | R/W-0 | R/W-0
| | | | | GAMMAGP3 <2 - 0>

❑ GAMMAGPx Gamma curve selector for the GPx pins

000: Gamma 1

001: Gamma 1.8

010: Gamma 2.0

011: Gamma 2.2

100: Gamma 2.4

101: Gamma 2.6

110: Gamma 2.8

## 2.8 I2CNavKey unique code

This register contains an unique code that it’s used to identify the I2CNavKeyThis register is only readable and not ˙ writable.

IDCODE Address: 0x70
7 | 6 | 5 | 4 | 3 | 2 | 1 | 0
R-0 | R-1 | R-0 | R-1 | R-1 | R-0 | R-1 | R-1
IDCODE = 0x5B

## 2.9 I2CNavKey version

This register contains the version of the I2CNavKeyThis value will change in case of a new hardware or firmware ˙ release. This register is only readable and not writable.

VERSION Address: 0x71
7 | 6 | 5 | 4 | 3 | 2 | 1 | 0
R-0 | R-0 | R-0 | R-1 | R-0 | R-0 | R-0 | R-1
Version = 0x12

# 3. Reference

This project is open source, the HW and the FW as well as some examples can be found on GitHub: https://github.com/Fattoresaimon/I2CNavKey

# 4. Issues

# 5. Changelog

In this chapter there are the hardware and firmware changes between the board version.

## I2C NavKey HW1.2:

Hardware changes:

- Changed the CON1 connector from JST XH-5 to JST PH-5
- Changed the CON1 pinout

Firmware changes: No firmware changes

# 6. Schematic

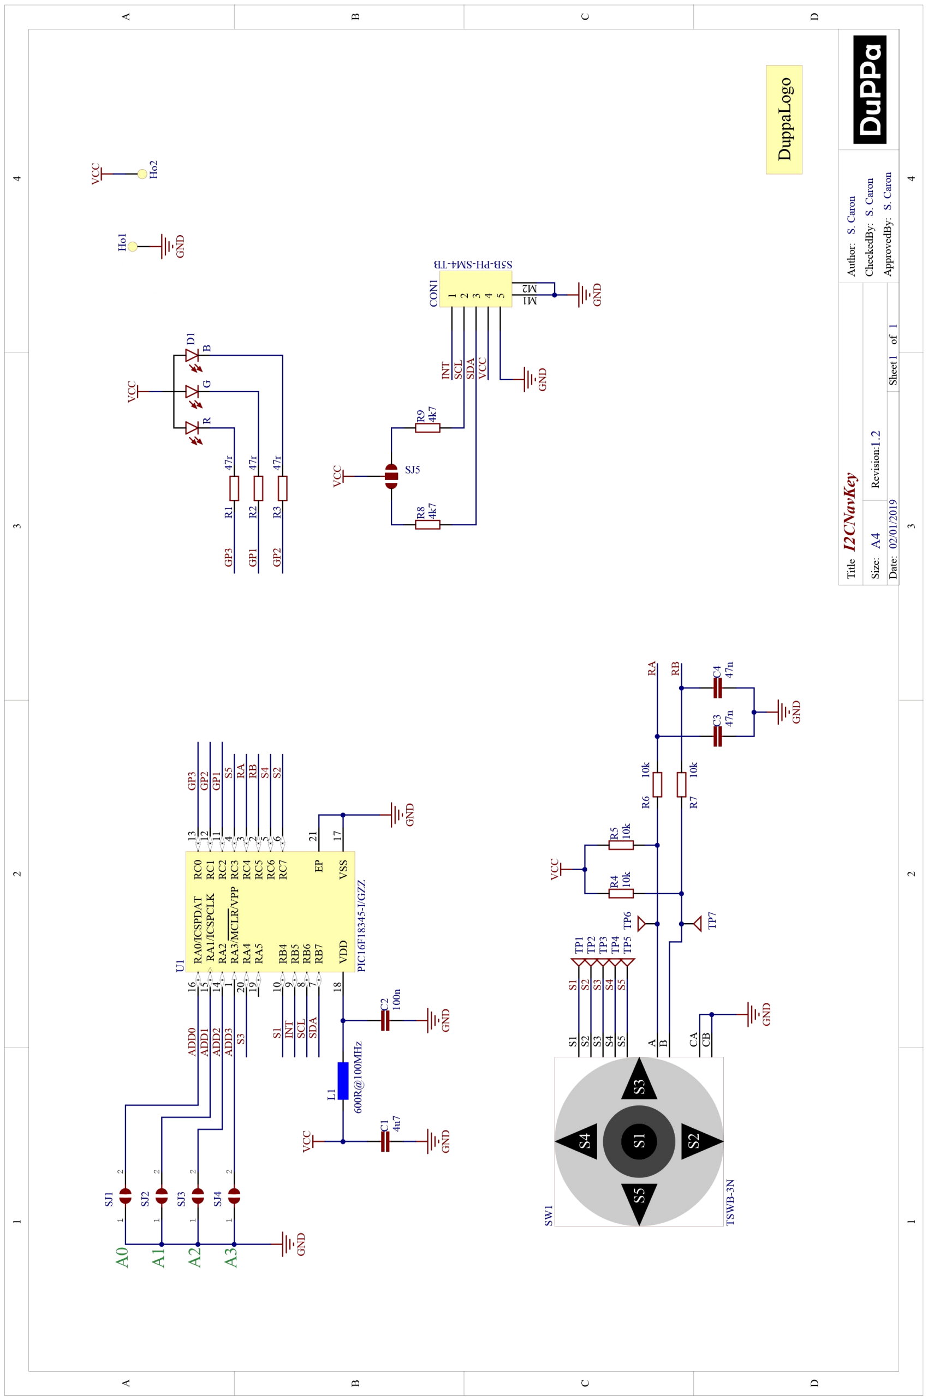
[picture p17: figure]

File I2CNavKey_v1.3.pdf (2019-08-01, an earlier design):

www.duppa.net

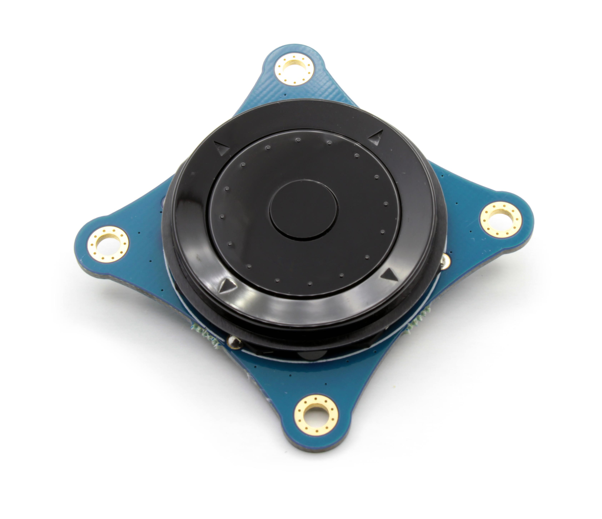
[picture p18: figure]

# I2CNavKey

## HW V1.1

August 1, 2019

Document written in LATEX

www.duppa.net | I2CNavKey

# Revision History

Revision | Date | Author(s) | Description
1.3 | 01.08.19 | Simone | Small changes on this document layout
1.2 | 09.07.19 | Simone | Fixed the numbering of the gamma type
1.1 | 26.05.19 | Simone | Added the pull-up resistors jumpers and new photos
1.0 | 08.04.19 | Simone | First version

# Contents

1 Device Overview | 3
2 Registers | 13
3 Reference | 28
4 Issues | 29
5 Schematic | 30

# 1. Device Overview

The I2CNavKey is a small board that includes a 7 functions joypad.
The joypad has 4 directional keys plus a central button and a rotary ring. It is controllable with the I²C bus, and it’s possible to configure 16 different I²C addresses.

The I2CNavKey has also 3 configurable GPIOs with the same footprint of RGB LED. This 3 GPIOs can be configured independently in 4 different way: input, output, PWM and analog input.

Since the I2CNavKey is a I²C slave, it has a series of 8 bit registers where it’s possible to configure different parameters, it’s also possible to detect when the buttons are pressed or when the ring is rotated.
It also has an open-drain output pin used as interrupt output. This pin is used to notify to the master when some event happens in the I2CNavKey, the source of interrupt can be customized.

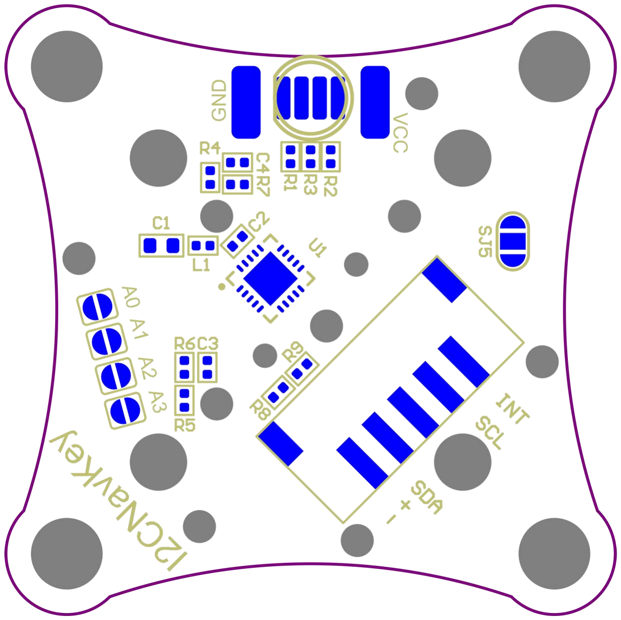
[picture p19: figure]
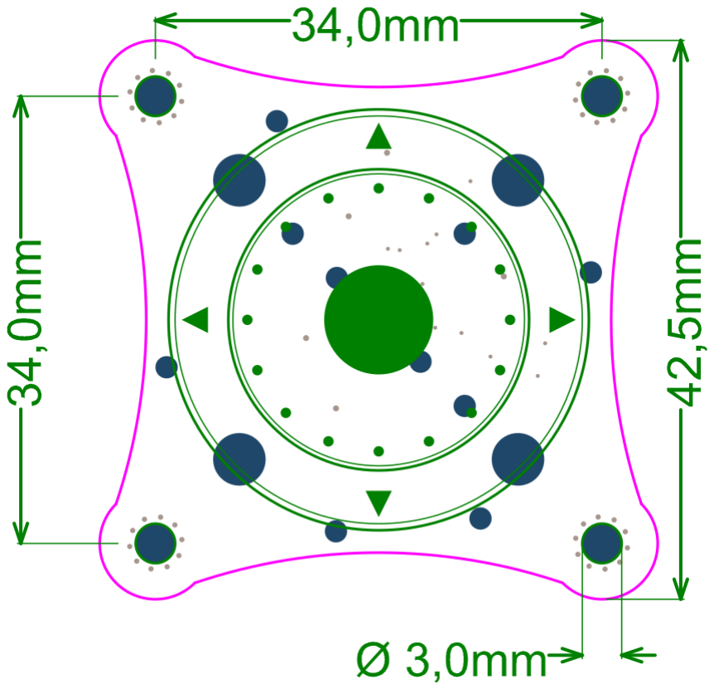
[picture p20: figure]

Figure 1.1: Dimension | Figure 1.2: Bottom view of the board


Figure 1.3: Dimension of the joypad: TSWB-3N-CB222 LFS from C&K

## 1.1 Electrical characteristics

Parameter | Symbol | Min | Max
Supply voltage | VDD | 3V | 5V
2C input-low level I | VIL | 0 | 0.3 * VDD
2C input-high level I | VIH | 0.8 * VDD | VDD
2C clock input frequency I | fSCL | | 400kHz
Supply current (LEDs off) | IDD | | 1.8mA
Interrupt pull-up resistor | RINT | 15kΩ | 120kΩ

## 1.2 Connection

Figure 1.4 shows the pin-out of the I2CNavKey.

Pin | I/O Type | Function
GND | Power | Ground reference for logic
Vcc | Power | Positive supply for logic
SDA | I/O | 2C data I
SCL | I | 2C clock I
INT | OD | Open-drain interrupt output

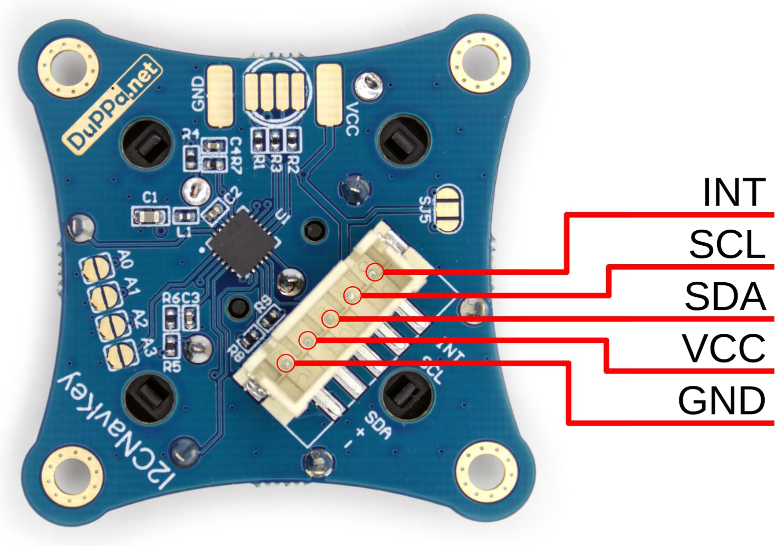
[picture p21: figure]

Figure 1.4: Pinout of the board

There are a 5 pins JST XH connector where it is possible to connect the I2CNavKey to the master. In order to avoid I

2C address conflict with other devices on the bus, the address of each device must be different. In the section 1.3, it is described how to set the address.

## 1.3 I

## 2C interface

The I2CNavKey is a I²C slave, it’s possible to the set 16 different addresses. All of the 7-bit address can be customized by soldering the jumpers A0 - A3 on the bottom of the board. When the jumper is open, it means a logic 0. if jumper is shorted it means a logic 1.

I

2C address

7 | 6 | 5 | 4 | 3 | 2 | 1 | 0
0 | 0 | 1 | A3 | A2 | A1 | A0 | R/W

For example in the figure 1.6 the jumper A0 and A2 are shorted and the 7-bit I²C address is 21 in decimal or 0x15 in hexadecimal or 0b00010101 in binary.

The I2CNavKey has I²C pull-up resistors, by default they are not enabled. In order to enable the resistor the jumper SJ5 must be soldered.
This must be done in case that the master doesn’t have these resistors and must be enabled only one I2CNavKey in a chain. A typical value of this resistors are 4.7kΩ.
In the figure 1.6 is showed how to short the jumper SJ5.

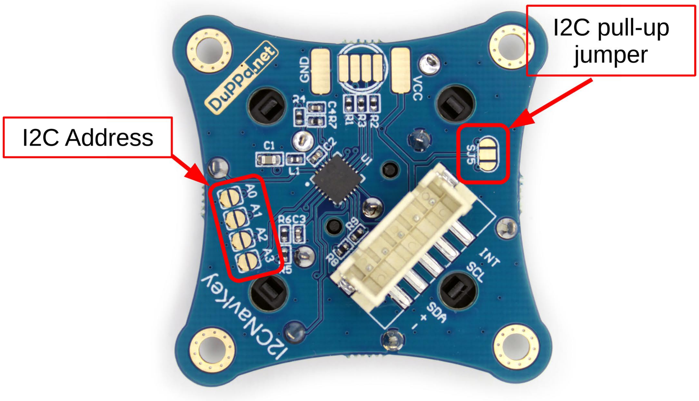
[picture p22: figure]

Figure 1.5: Jumper location of the pull-up resistor and of the address

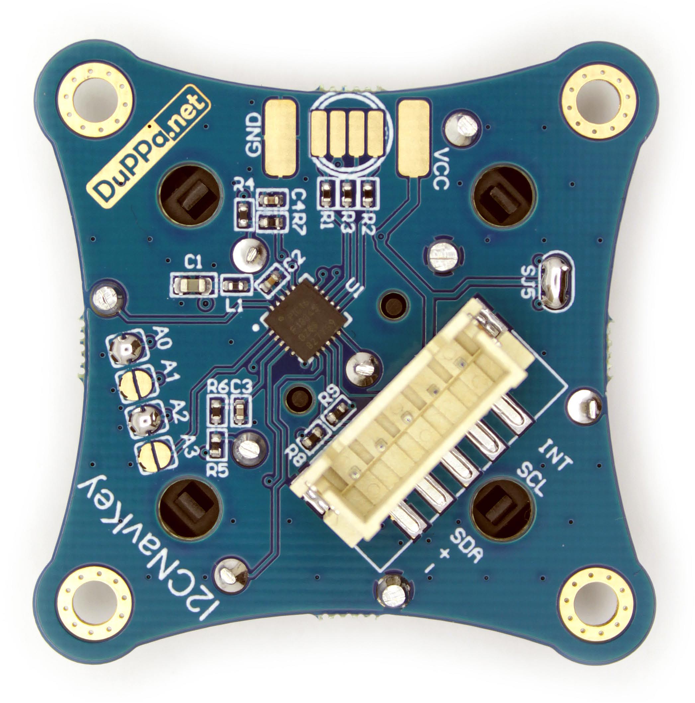
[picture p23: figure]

Figure 1.6: Example of jumper soldered: A0 and A2 shorted and also the SJ5 is shorted enabling the pull-up resistors

## 1.4 Joypad

On the I2CNavKey, there is a joypad with 7 functions:

- 4 directional buttons: up, down, left and right
- 1 central button
- Central wheel that can be rotated left and right, and it has 12 pulses per rotation.


Figure 1.7: 7 function of the joypad

### 1.4.1 Buttons

When a button is pressed, the specific bit is set in the register ISTATUS. Every button has 2 specific bits because it’s possible to detect when the button is pressed and when is released.
The central button has also the possibility to read a fast double push by setting a window time in the register DPPERIOD. When a double push is made inside of the DPPERIOD window, the bit SCTRDP is set and it is possible to read in the ISTATUS register.
If the DPPERIOD is 0, the double push function is disabled.

### 1.4.2 Encoder

For reading the rotary encoder movement, there are 4 of 32bit registers: CVAL, CMAX, CMIN and ISTEP. All of these 4 registers can be configured to work as 32bit int or as IEEE 754 floating number, this format can be set in the GCONF register.
The counter limits are the following:
- 32bit INT: from −2147483648 to +2147483647
- IEEE 754 float: from −126.0 to +127.0

In case of 32bit int, it is not necessary to read all the 4 bytes, you can read only the first 8 bit or the first 16 bit. For example, if you want to count between 0 and 10, you can read only the first byte of the CVAL register. In this way, you can save I2C transactions.
Every time the encoder moves one step, the value of the CVAL register is increased or decreased of the value of ISTEP. The direction of the rotation decides if ISTEP is added or subtracted from CVAL.
CMAX and CMIN are used for setting a minimum and maximum thresholds of CVAL. In the GCONF register, there is WRAPE bit. This bit is used to enable or disable a wrap functionality of CVAL when it exceeds from the thresholds.
For example, if i configure the I2CNavKey as following:
- CVAL= 0
- CMAX = 5
- CMIN = -5
- ISTEP= 1

I will have CVAL is incremented of 1 at each rotation step of the encoder. The maximum value that CVAL can reach will be 5 while the minimum is -5. In the figure 1.8 shows the value of CVAL.

As showed in the figure 1.9, when WRAPE is set to 1 when CVAL reaches the value of 5, at the next increment CVAL it will be wrapped to -5.
Every time when the encoder is rotated one step and when CVAL reaches the thresholds, an interrupt is generated and it is possible to read in the register ISTATUS.


Figure 1.8: Blue and red lines are the CVAL values when the encoder is rotated and the WRAPE is disabled


Figure 1.9: Blue and red line are the CVAL values when the encoder is rotate and the WRAPE is enabled

## 1.5 GP pins

There are 3 configurable GP pins, they are called GP1, GP2 and GP3. They have the same footprint of an 5mm RGB led. In figure 1.10, it is shown the position. Each pin can be configured to be:

- PWM: The pins is configured to be a PWM output.
- Analog input: The pins is configured to be an input of the internal ADC.
- GPIO output: The pins is configured to be a digital output.
- GPIO Input: The pin is configured to be a digital input.

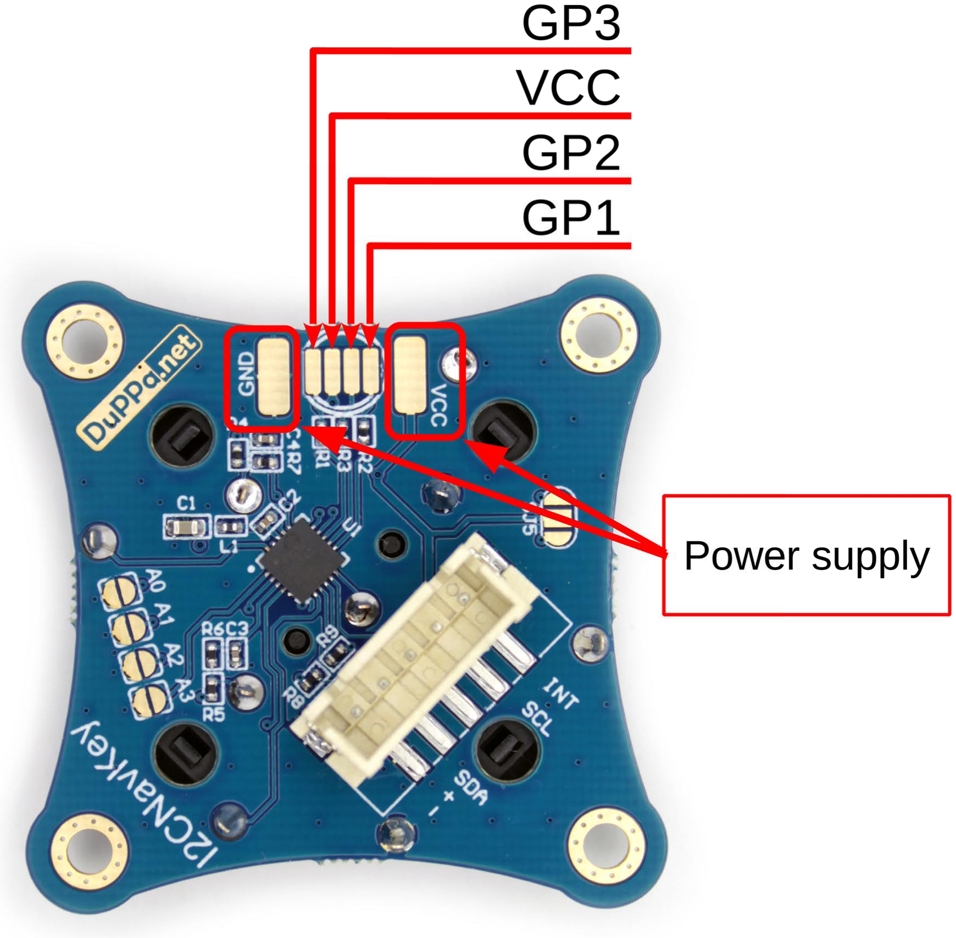
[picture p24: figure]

Figure 1.10: GP pins pinout

### 1.5.1 PWM mode

A GP pins can be configured in PWM mode by configuring the GPxMODE 1
to 0x00. The default configuration of the GP pins at the start up is PWM. Once the GP pin is configure in PWM mode, it is possible to set the PWM value by writing the corresponding GPxREG.
The PWM is resolution 10bit with a frequency of 31.25kHz, but the user can not access to the full resolution. It is possible to set a PWM value between 0% to 100% by writing 0 to 100 to the GPxREG.
The PWM is inverted, this means that when the PWM is 0% the GP pin voltage is VCC while when it is 100% the GP pin is GND.
In this way it is possible to connect a common anode RGB LED and have the LED off when the PWM is 0 and full on when the PWM is 100.
To each PWM outputs it is possible to configure a specific gamma correction by writing the register GAMMAGPx. There are 7 type of gamma correction:

✥ Gamma 1 (linear)

✥ Gamma 1.8

✥ Gamma 2.0

✥ Gamma 2.2

✥ Gamma 2.4

✥ Gamma 2.6

✥ Gamma 2.8

In the figure 1.11 is showed the relationship between the PWM at the full resolution and the PWM settable from the user.

1
In a register name the x correspond to 1, 2 or 3

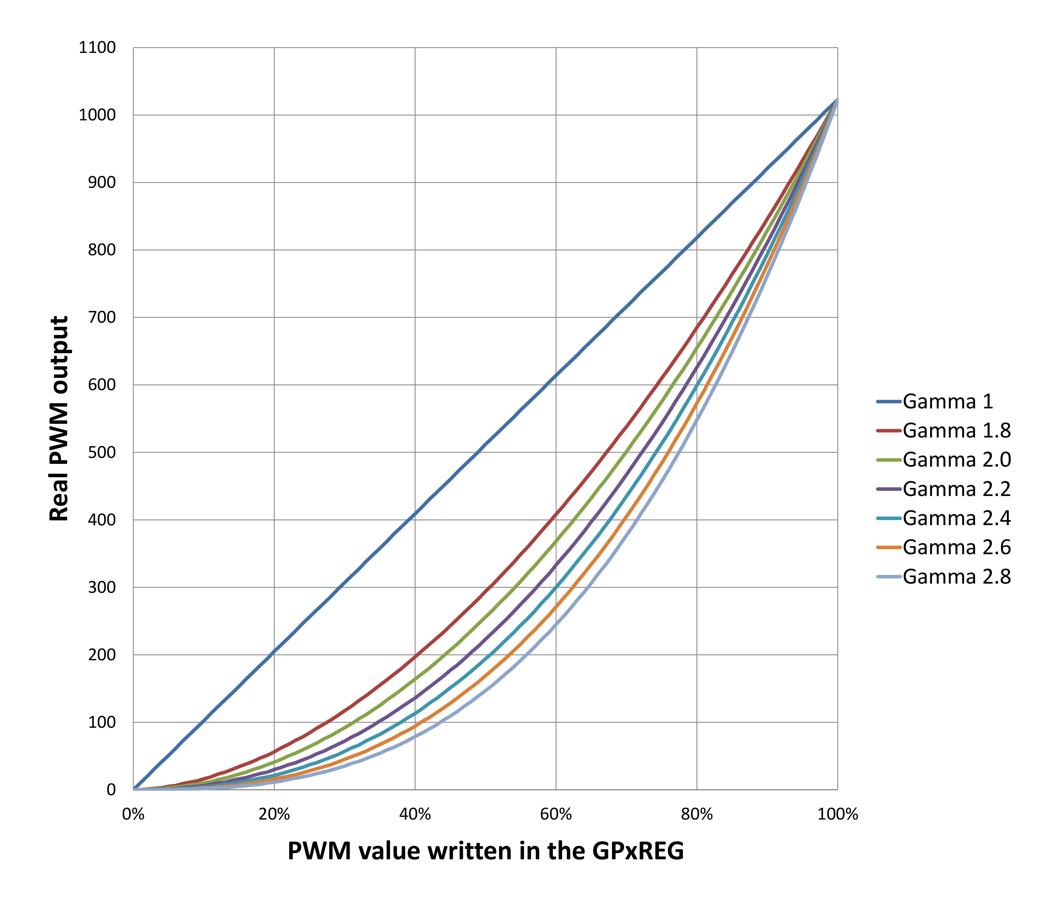
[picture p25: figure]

Figure 1.11: Possible gamma option

Fade function

The I2CNavKey has an auto fading features.
There is the register FADEGP, the value you write inside these registers is the step speed of the fading ramp, and it’s in ms. The fading will follow the selected gamma correction. If the value is 0, the fade feature is disabled. It means that when the new value of PWM is written, it is immediately updated to the output.
The fading process starts when a PWM value is written. Fading process is complete according to the PWM value you have set. When the internal fade PWM value is the same of the PWM value (it means that when fading is complete), an interrupt will be generated. Let’s make an example:

At the startup, i write as:

- GP1REG = 0
- GP2REG = 0
- GP3REG = 0
- FADEGP = 1

In above case, the LEDs of the encoder are off and the fade has 1ms step size.
Now i write as: GP1REG=100.
This moment, the ramp of the GP1REG starts and reaches the value 0x100 in 100ms. (the other LEDs remain OFF) When the ramp reaches 100, i get an interrupt from the INT pin.
After this, i write as: GP1REG=0x00. At this point, the fade ramp starts again and it will turn off the LED in 100ms, and an interrupt will be generated at the end.
The figure 1.12 is showing an example of the fade output when a PWM value is written in different moments, as well as when the interrupt of the fade is generated.


Figure 1.12: Time diagram of the fade output when writing on the PWM register

### 1.5.2 OUT mode

A GP pin can be configured as output mode by configuring the GPxMODE to 0x01. When the pin is configured as output writing 1 to GPxREG it make the GP pin high, while writing 0 make the pin low.

### 1.5.3 ADC mode

A GP pin can be configured as ADC mode by configuring the GPxMODE to 0x02. It is possible to read the ADC value by reading the register GPxREG. The content of the register updates every 10ms. When the GP pin is tied to 0 the ADC value is 0, while when the GP pin is tied to VCC the ADC value is 255. In this case it is also possible to enable the internal pull-up by writing 1 in the GPxPUL field.

### 1.5.4 IN mode

A GP pin can be configured as input mode by configuring the GPxMODE to 0x03. In this case, it is also possible to enable the internal pull-up by writing 1 in the GPxPUL field. It is also possible to configure the GP pin to generate an interrupt when the signal change. In the field GPxINT it possible to enable the interrupt when there is a positive edge, negative edge or both. The interrupt can be read in the register I2STATUS.It can be also reported to the INT pin by enabling the SINT2L bit.

## 1.6 EEPROM

The I2CNavKey has 256 bytes of EEPROM.
This memory is divided in two banks of 128 bytes. With the bit MBANK in the GCONF register, it is possible to choose either the bank 1 or the bank 2.
The memory area is between 0x80 and 0xFF address. To use the EEPROM, user only needs to perform reading or a writing in these address areas.
The writing time takes 4 - 5ms to be executed. Wait this time before sending other commands.

## 1.7 Interrupt

The I2CNavKey has multiple interrupt source previously described. When an interrupt is generated, the INT pin is tied low. By reading the register ISTATUS, the interrupts are cleared and the INT pin returns high.

The INT pin is open-drain output. Hence it requires an external pull-up resistor, or internal pull-up resistor can be enabled by setting the bit IPUD to 1.
In a chain of I2CNavKey all the INT pins can be connected together, like the pin of the I²C. When an interrupt occurs, user has to scan the boards in the chain to find who generates the interrupt.
With the register INTCONF, it is possible to enable or disable interrupt. When an interrupt is disabled, the corresponding bit is set, but the INT pin is not affected.

# 2. Registers

In this section, the internal registers of I2CNavKey is described.
The I2CNavKey has the auto increment feature. This means that after writing or reading a register, the internal address pointer is automatically incremented by one.
Address range | Name | Description | Dimension | Default value
0x00 | GCONF | General Configuration | 1 Byte | 0
0x01 | GP1CONF | GP 1 Configuration | 1 Byte | 0
0x02 | GP2CONF | GP 2 Configuration | 1 Byte | 0
0x03 | GP3CONF | GP 3 Configuration | 1 Byte | 0
0x04 0x05 | INTCONF | INT pin Configuration | 2 Byte | 0
0x06 - 0x07 | ISTATUS | Interrupt Status | 2 Byte | 0
0x08 | I2STATUS | Secondary interrupt status | 1 Byte | 0
0x09 | FSTATUS | Fade process status | 1 Byte | 0
0x0A - 0x0D | CVAL | Counter Value | 4 Byte | 0
0x0E - 0x11 | CMAX | Counter Max value | 4 Byte | 0
0x12 - 0x15 | CMIN | Counter Min value | 4 Byte | 0
0x16 - 0x19 | ISTEP | Increment step value | 4 Byte | 1
0x1A | GP1REG | I/O GP1 register | 1 Byte | 0
0x1B | GP2REG | I/O GP2 register | 1 Byte | 0
0x1C | GP3REG | I/O GP3 register | 1 Byte | 0
0x1D | DPPERIOD | Double push period | 1 Byte | 0
0x1E | FADEGP | Fade timer step of GPs ports | 1 Byte | 0
0x1F | GAMMAGP1 | Gamma correction on PWM of GP1 | 1 Byte | 0
0x20 | GAMMAGP2 | Gamma correction on PWM of GP2 | 1 Byte | 0
0x21 | GAMMAGP3 | Gamma correction on PWM of GP3 | 1 Byte | 0
0x70 | IDCODE | I2CNavKey unique code | 1 Byte | 0x5B
0x71 | VERSION | I2CNavKey version | 1 Byte | 0x11
0x80 - 0xFF | EEPROM | EEPROM memory | 128 Byte | 0

## 2.1 Configuration

### 2.1.1 General Configuration

GCONF Address: 0x00
7 | 6 | 5 | 4 | 3 | 2 | 1 | 0
R/W-0 | R/W-0 | R/W-0 | R/W-0 | R/W-0 | R/W-0 | R/W-0 | R/W-0
RESET | | MBANK | CKSRC | IPUD | DIRE | WRAPE | DTYPE

❖ DTYPE Data type of the register: CVAL, CMAX, CMIN and ISTEP.

1: The registers are considered float numbers IEEE 754

0: The registers are considered int 32bit

❖ WRAPE Enable counter wrap.

1: Wrap enable. When the counter value reaches the CMAX+1, restart to the CMIN and vice versa

0: Wrap disable. When the counter value reaches the CMAX or CMIN, the counter stops to increasing or decreasing

❖ DIRE Direction of the encoder when increment.

1: Rotate left side to increase the counter value

0: Rotate right side to increase the counter value

❖ IPUD Interrupt Pull-UP disable.

1: Disable

0: Enable

❖ CKSRC Enable or disable I²C clock stretch

1: Enabled

0: Disabled

❖ MBANK Select the EEPROM memory bank. Each bank are 128 byte wide

1: Second memory bank

0: First memory bank

❖ RST Reset of the I2CNavKey

1: Reset of the I2CNavKey. The RESET command takes 400us to be executed.

0: No reset

### 2.1.2 GP1 Configuration

GP1CONF Address: 0x01
7 | 6 | 5 | 4 | 3 | 2 | 1 | 0
R/W-0 | R/W-0 | R/W-0 | R/W-0 | R/W-0 | R/W-0 | R/W-0 | R/W-0
- | - | - | GP1INT | | GP1PUL | GP1MODE

❖ GP1MODE Configuration of the pin GP1

00: PWM output
01: GPIO output Push-Pull

10: Analog input
11: GPIO Input

❖ GP1PUL Enable or disable the internal pull-up.

0: Pull-UP disable

1: Pull-UP enabled

❖ GP1INT Configuration of the interrupt, available only when the pin is configured as input

00: Interrupt disabled

01: Interrupt on positive edge

10: Interrupt on negative edge

11: Interrupt on both edges

### 2.1.3 GP2 Configuration

GP2CONF Address: 0x02
7 | 6 | 5 | 4 | 3 | 2 | 1 | 0
R/W-0 | R/W-0 | R/W-0 | R/W-0 | R/W-0 | R/W-0 | R/W-0 | R/W-0
- | - | - | GP2INT | | GP2PUL | GP2MODE

❖ GP2MODE Configuration of the pin GP2

00: PWM output
01: GPIO output Push-Pull

10: Analog input
11: GPIO Input

❖ GP2PUL Enable or disable the internal pull-up.

0: Pull-UP disable

1: Pull-UP enabled

❖ GP2INT Configuration of the interrupt, available only when the pin is configured as input

00: Interrupt disabled

01: Interrupt on positive edge

10: Interrupt on negative edge

11: Interrupt on both edges

### 2.1.4 GP3 Configuration

GP3CONF Address: 0x03
7 | 6 | 5 | 4 | 3 | 2 | 1 | 0
R/W-0 | R/W-0 | R/W-0 | R/W-0 | R/W-0 | R/W-0 | R/W-0 | R/W-0
- | - | - | GP3INT | | GP3PUL | GP3MODE

❖ GP3MODE Configuration of the pin GP3

00: PWM output
01: GPIO output Push-Pull

10: Analog input
11: GPIO Input

❖ GP3PUL Enable or disable the internal pull-up.

0: Pull-UP disable

1: Pull-UP enabled

❖ GP3INT Configuration of the interrupt, available only when the pin is configured as input

00: Interrupt disabled

01: Interrupt on positive edge

10: Interrupt on negative edge

11: Interrupt on both edges

## 2.2 Interrupt output Configuration

This register is used to enable or disable the interrupt source selectively. When an interrupt event occurs, the INT pin goes low and the event is stored in the status register.

INTCONF Address: 0x04
15 | 14 | 13 | 12 | 11 | 10 | 9 | 8
R/W-0 | R/W-0 | R/W-0 | R/W-0 | R/W-0 | R/W-0 | R/W-0 | R/W-0
INT2 | IRMIN | IRMAX | IRDEC | IRINC | ICTRDP | ICTRP | ICTRR
Address: 0x05
7 | 6 | 5 | 4 | 3 | 2 | 1 | 0
R/W-0 | R/W-0 | R/W-0 | R/W-0 | R/W-0 | R/W-0 | R/W-0 | R/W-0
ILTP | ILTR | IRTP | IRTR | IDNP | IDNR | IUPP | IUPR

❖ IUPR Button UP release bit

1: Interrupt enabled when the UP button is released.

0: Interrupt disabled

❖ IUPP Button UP press bit

1: Interrupt enabled when the UP button is pressed.

0: Interrupt disabled

❖ IDNR Button DOWN release bit

1: Interrupt enabled when the DOWN button is released.

0: Interrupt disabled

❖ IDNP Button DOWN press bit

1: Interrupt enabled when the DOWN button is pressed.

0: Interrupt disabled

❖ IRTR Button RIGHT release bit

1: Interrupt enabled when the RIGHT button is released.

0: Interrupt disabled

❖ IRTP Button RIGHT press bit

1: Interrupt enabled when the RIGHT button is pressed.

0: Interrupt disabled

❖ ILTR Button LEFT release bit

1: Interrupt enabled when the LEFT button is released.

0: Interrupt disabled

❖ ILTP Button LEFT press bit

1: Interrupt enabled when the LEFT button is pressed.

0: Interrupt disabled

❖ ICTRR CENTRAL button release bit

1: Interrupt enabled when the CENTRAL button is released.

0: Interrupt disabled

❖ ICTRP Push button press bit

1: Interrupt enabled when the CENTRAL button is pressed.

0: Interrupt disabled

❖ ICTRDP CENTRAL button double press

1: Interrupt enabled when the CENTRAL button is double pressed.

0: Interrupt disabled

❖ IRINC Rotary encoder direction of increase

1: Interrupt enabled when the encoder is rotated in the direction of increase

0: Interrupt disabled

❖ IRDEC Rotary encoder direction of decrease

1: Interrupt enabled when the encoder is rotated in the direction of decrease

0: Interrupt disabled

❖ IRMAX CVAL reaches CMAX bit

1: Interrupt enabled when CVAL reaches CMAX

0: Interrupt disabled

❖ IRMIN CVAL reaches CMIN bit

1: Interrupt enabled when CVAL reaches CMIN

0: Interrupt disabled

❖ INT2 Enable the secondary interrupts

1: Secondary interrupt enabled

0: Secondary interrupt disabled

## 2.3 Status

### 2.3.1 I2CNavKey Status

This register is only readable, when is read is automatically cleared.

ISTATUS Address: 0x06
15 | 14 | 13 | 12 | 11 | 10 | 9 | 8
R/W-0 | R/W-0 | R/W-0 | R/W-0 | R/W-0 | R/W-0 | R/W-0 | R/W-0
SINT2 | SRMIN | SRMAX | SRDEC | SRINC | SCTRDP | SCTRP | SCTRR
Address: 0x07
7 | 6 | 5 | 4 | 3 | 2 | 1 | 0
R/W-0 | R/W-0 | R/W-0 | R/W-0 | R/W-0 | R/W-0 | R/W-0 | R/W-0
SLTP | SLTR | SRTP | SRTR | SDNP | SDNR | SUPP | SUPR

❑ SUPR Button UP release bit

1: UP button is released

0: UP button is not released

❑ SUPP Button UP press bit

1: UP button is pressed

0: UP button is not pressed

❑ SDNR Button DOWN release bit

1: DOWN button is released

0: DOWN button is not released

❑ SDNP Button DOWN press bit

1: DOWN button is pressed

0: DOWN button is not pressed

❑ SRTR Button RIGHT release bit

1: RIGHT button is released

0: RIGHT button is not released

❑ SRTP Button RIGHT press bit

1: RIGHT button is pressed

0: RIGHT button is not pressed

❑ SLTR Button LEFT release bit

1: LEFT button is released

0: LEFT button is not released

❑ SLTP Button LEFT press bit

1: LEFT button is pressed

0: LEFT button is not released

❑ SCTRR CENTRAL button release bit

1: CENTRAL button is released

0: CENTRAL button is not released

❑ SCTRP CENTRAL button press bit

1: CENTRAL button is pressed

0: CENTRAL button is not pressed

❑ SCTRDP CENTRAL button double press

1: CENTRAL button is double pressed

0: CENTRAL button is not double pressed

❑ RINC Rotary encoder is rotated in the increase direction

1: Encoder is rotated

0: Encoder is not rotated

❑ RDEC Rotary encoder is rotated in the decrease direction

1: Encoder is rotated

0: Encoder is not rotated

❑ RMAX Status of the counter value

1: CVAL reaches the CMAX value

0: CVAL is below the CMAX value

❑ RMIN Status of the counter value

1: CVAL reaches the CMIN value

0: CVAL is above the CMIN value

❑ SINT2 Secondary interrupt status

1: Secondary interrupt event occurs

0: No secondary event occurs

### 2.3.2 Secondary interrupt status

In this register is possible to check the event of the fade process as well as the GP pins when is configured as input. This register if only readable, when is read is automatically cleared.

I2STATUS Address: 0x08
7 | 6 | 5 | 4 | 3 | 2 | 1 | 0
R-0 | R-0 | R-0 | R-0 | R-0 | R-0 | R-0 | R-0
- | FADE | EGP3 | | EGP2 | | EGP1

❑ GP1 Interrupt on the GP1 port.

00: No event occurs

01: Positive edge event

10: Negative edge event

❑ GP2 Interrupt on the GP2 port.

00: No event occurs

01: Positive edge event

10: Negative edge event

❑ GP3 Interrupt on the GP3 port.

00: No event occurs

01: Positive edge event

10: Negative edge event

❑ FADE Fade process interrupt.

1: Fade process event

0: No event in the fade process

### 2.3.3 Fade process status

With this register is possible to check the status of the PWM channel during the fade process. This register is only readable and the bits are set or cleared automatically during the fade process.

FSTATUS Address: 0x09
7 | 6 | 5 | 4 | 3 | 2 | 1 | 0
R-0 | R-0 | R-0 | R-0 | R-0 | R-0 | R-0 | R-0
- | - | - | - | - | FGP3 | FGP2 | FGP1

❑ FGP1 Fade status process of the GP1

1: Fade process is running

0: Fade process terminated

❑ FGP2 Fade status process of the GP2

1: Fade process is running

0: Fade process terminated

❑ FGP3 Fade status process of the GP3

1: Fade process is running

0: Fade process terminated

## 2.4 Encoder registers

These 4 registers are in 32bit format. It is possible to read/write a single byte independently, no need to read/write all the 4 bytes at time.
They can be also used in float mode IEEE 754, but the DTYPE bit must be set.

### 2.4.1 Counter Value

CVAL Address: 0x0A
31 | 30 | 29 | 28 | 27 | 26 | 25 | 24
R/W-0 | R/W-0 | R/W-0 | R/W-0 | R/W-0 | R/W-0 | R/W-0 | R/W-0
CVAL BYTE 4 <31 - 24>
Address: 0x0B
23 | 22 | 21 | 20 | 19 | 18 | 17 | 16
R/W-0 | R/W-0 | R/W-0 | R/W-0 | R/W-0 | R/W-0 | R/W-0 | R/W-0
CVAL BYTE 3 <23 - 16>
Address: 0x0C
15 | 14 | 13 | 12 | 11 | 10 | 9 | 8
R/W-0 | R/W-0 | R/W-0 | R/W-0 | R/W-0 | R/W-0 | R/W-0 | R/W-0
CVAL BYTE 2 <15 - 8>
Address: 0x0D
7 | 6 | 5 | 4 | 3 | 2 | 1 | 0
R/W-0 | R/W-0 | R/W-0 | R/W-0 | R/W-0 | R/W-0 | R/W-0 | R/W-0
CVAL BYTE 1 <7 - 0>

### 2.4.2 Counter Max

CMAX Address: 0x0E
31 | 30 | 29 | 28 | 27 | 26 | 25 | 24
R/W-0 | R/W-0 | R/W-0 | R/W-0 | R/W-0 | R/W-0 | R/W-0 | R/W-0
CMAX BYTE 4 <31 - 24>
Address: 0x0F
23 | 22 | 21 | 20 | 19 | 18 | 17 | 16
R/W-0 | R/W-0 | R/W-0 | R/W-0 | R/W-0 | R/W-0 | R/W-0 | R/W-0
CMAX BYTE 3 <23 - 16>
Address: 0x10
15 | 14 | 13 | 12 | 11 | 10 | 9 | 8
R/W-0 | R/W-0 | R/W-0 | R/W-0 | R/W-0 | R/W-0 | R/W-0 | R/W-0
CMAX BYTE 2 <15 - 8>
Address: 0x11
7 | 6 | 5 | 4 | 3 | 2 | 1 | 0
R/W-0 | R/W-0 | R/W-0 | R/W-0 | R/W-0 | R/W-0 | R/W-0 | R/W-0
CMAX BYTE 1 <7 - 0>

### 2.4.3 Counter Min

CMIN Address: 0x12
31 | 30 | 29 | 28 | 27 | 26 | 25 | 24
R/W-0 | R/W-0 | R/W-0 | R/W-0 | R/W-0 | R/W-0 | R/W-0 | R/W-0
CMIN BYTE 4 <15 - 8>
Address: 0x13
23 | 22 | 21 | 20 | 19 | 18 | 17 | 16
R/W-0 | R/W-0 | R/W-0 | R/W-0 | R/W-0 | R/W-0 | R/W-0 | R/W-0
CMIN BYTE 3 <7 - 0>
Address: 0x14
15 | 14 | 13 | 12 | 11 | 10 | 9 | 8
R/W-0 | R/W-0 | R/W-0 | R/W-0 | R/W-0 | R/W-0 | R/W-0 | R/W-0
CMIN BYTE 2 <15 - 8>
Address: 0x15
7 | 6 | 5 | 4 | 3 | 2 | 1 | 0
R/W-0 | R/W-0 | R/W-0 | R/W-0 | R/W-0 | R/W-0 | R/W-0 | R/W-0
CMIN BYTE 1 <7 - 0>

### 2.4.4 Increment step

ISTEP Address: 0x16
31 | 30 | 29 | 28 | 27 | 26 | 25 | 24
R/W-0 | R/W-0 | R/W-0 | R/W-0 | R/W-0 | R/W-0 | R/W-0 | R/W-0
ISTEP BYTE 4 <15 - 8>
Address: 0x17
23 | 22 | 21 | 20 | 19 | 18 | 17 | 16
R/W-0 | R/W-0 | R/W-0 | R/W-0 | R/W-0 | R/W-0 | R/W-0 | R/W-0
ISTEP BYTE 3 <7 - 0>
Address: 0x18
15 | 14 | 13 | 12 | 11 | 10 | 9 | 8
R/W-0 | R/W-0 | R/W-0 | R/W-0 | R/W-0 | R/W-0 | R/W-0 | R/W-0
ISTEP BYTE 2 <15 - 8>
Address: 0x19
7 | 6 | 5 | 4 | 3 | 2 | 1 | 0
R/W-0 | R/W-0 | R/W-0 | R/W-0 | R/W-0 | R/W-0 | R/W-0 | R/W-0
ISTEP BYTE 1 <7 - 0>

## 2.5 GPs registers

The usage of these register depends of the configuration of the GP pins:

- PWM Is possible to write the PWM value: 0 to 100.
- GPIO output: Is possible to write 1 or 0 for setting the output logic level.
- Analog input: Is possible to read the ADC value: 8 bit format.
- GPIO Input: Is possible to read the logic level of the output.

### 2.5.1 GP1 register

GP1REG Address: 0x1A
7 | 6 | 5 | 4 | 3 | 2 | 1 | 0
R/W-0 | R/W-0 | R/W-0 | R/W-0 | R/W-0 | R/W-0 | R/W-0 | R/W-0
GP1 Value <7 - 0>

### 2.5.2 GP2 register

GP2REG Address: 0x1B
7 | 6 | 5 | 4 | 3 | 2 | 1 | 0
R/W-0 | R/W-0 | R/W-0 | R/W-0 | R/W-0 | R/W-0 | R/W-0 | R/W-0
GP2 Value <7 - 0>

### 2.5.3 GP3 register

GP3REG Address: 0x1C
7 | 6 | 5 | 4 | 3 | 2 | 1 | 0
R/W-0 | R/W-0 | R/W-0 | R/W-0 | R/W-0 | R/W-0 | R/W-0 | R/W-0
GP3 Value <7 - 0>

## 2.6 Timing registers

This register are used for changing some timing parameter

### 2.6.1 Double push time

This register is used for setting the interval for the detection of the double push of the central button. The value is in ms × 10. When this register is 0 this function is disabled.

DPPERIOD Address: 0x1D
7 | 6 | 5 | 4 | 3 | 2 | 1 | 0
R/W-0 | R/W-0 | R/W-0 | R/W-0 | R/W-0 | R/W-0 | R/W-0 | R/W-0
PDPUSH <7 - 0>

### 2.6.2 Fade GP ports

This register is used for setting the fade speed of the GP ports. The value is in ms and indicate the time of one step. This register is working only if the GP port are configured in PWM

FADEGP Address: 0x1E
7 | 6 | 5 | 4 | 3 | 2 | 1 | 0
R/W-0 | R/W-0 | R/W-0 | R/W-0 | R/W-0 | R/W-0 | R/W-0 | R/W-0
FADEGP <7 - 0>

## 2.7 Gamma correction

This register is used for applying a gamma correction in case the GP port is used as PWM. It can be very useful when a LED is connected.

GAMMAGP1 Address: 0x1F
7 | 6 | 5 | 4 | 3 | 2 | 1 | 0
- | - | - | - | - | R/W-0 | R/W-0 | R/W-0
| | | | | GAMMAGP1 <2 - 0>

GAMMAGP2 Address: 0x20
7 | 6 | 5 | 4 | 3 | 2 | 1 | 0
- | - | - | - | - | R/W-0 | R/W-0 | R/W-0
| | | | | GAMMAGP2 <2 - 0>

GAMMAGP3 Address: 0x21
7 | 6 | 5 | 4 | 3 | 2 | 1 | 0
- | - | - | - | - | R/W-0 | R/W-0 | R/W-0
| | | | | GAMMAGP3 <2 - 0>

❑ GAMMAGPx Gamma curve selector for the GPx pins

000: Gamma 1

001: Gamma 1.8

010: Gamma 2.0

011: Gamma 2.2

100: Gamma 2.4

101: Gamma 2.6

110: Gamma 2.8

## 2.8 I2CNavKey unique code

This register contains an unique code that it’s used to identify the I2CNavKeyThis register is only readable and not ˙ writable.

IDCODE Address: 0x70
7 | 6 | 5 | 4 | 3 | 2 | 1 | 0
R-0 | R-1 | R-0 | R-1 | R-1 | R-0 | R-1 | R-1
IDCODE = 0x5B

## 2.9 I2CNavKey version

This register contains the version of the I2CNavKeyThis value will change in case of a new hardware or firmware ˙ release. This register is only readable and not writable.

VERSION Address: 0x71
7 | 6 | 5 | 4 | 3 | 2 | 1 | 0
R-0 | R-0 | R-0 | R-1 | R-0 | R-0 | R-0 | R-1
Version = 0x11

# 3. Reference

This project is open source, the HW and the FW as well as some examples can be found on GitHub: https://github.com/Fattoresaimon/I2CNavKey

# 4. Issues

# 5. Schematic

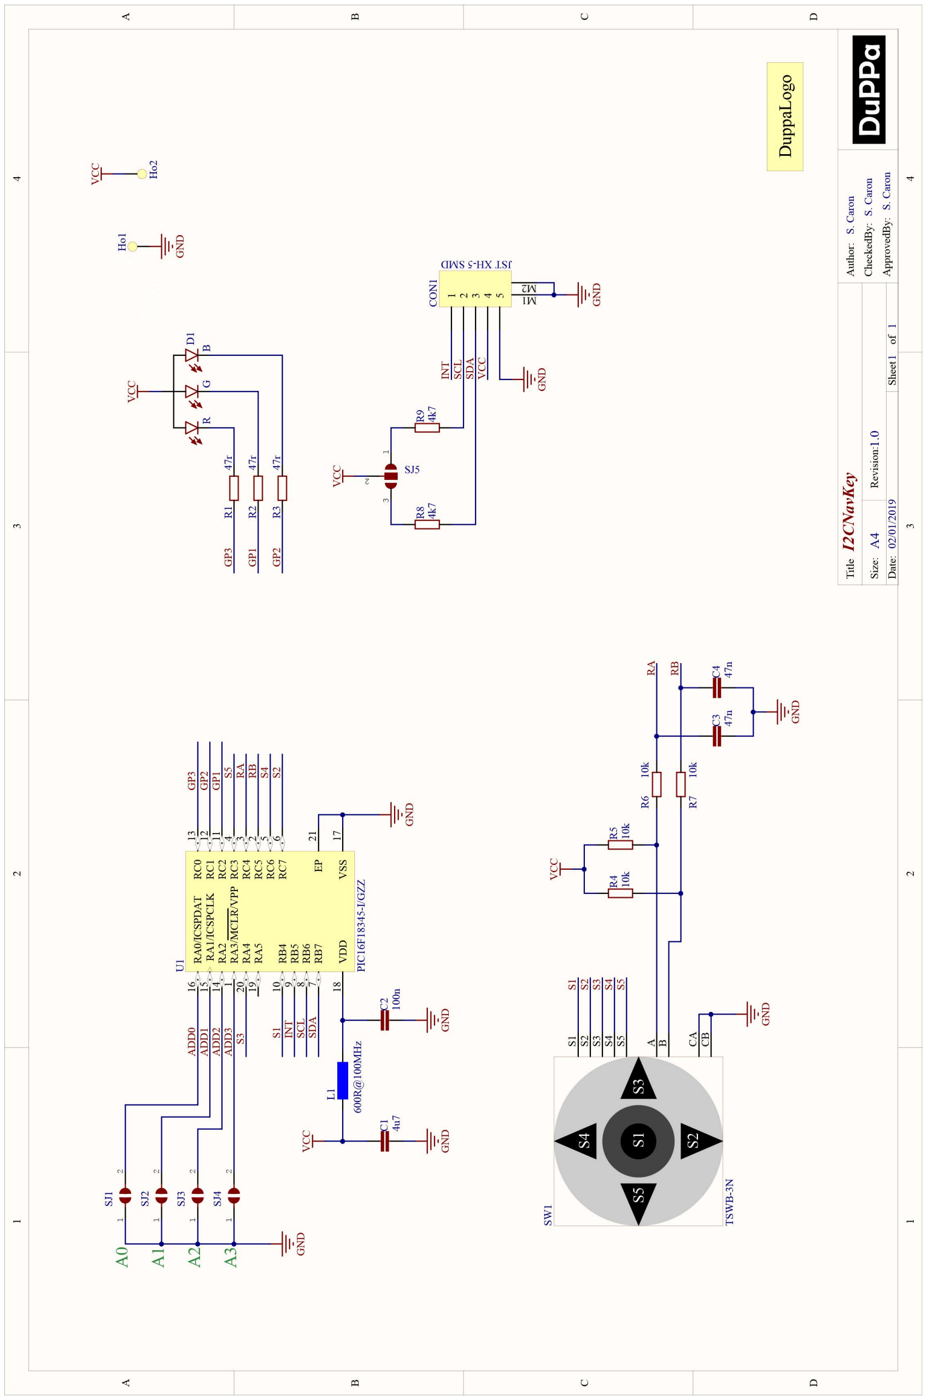
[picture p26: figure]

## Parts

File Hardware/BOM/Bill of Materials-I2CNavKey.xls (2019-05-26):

Description | Designator | Value | Footprint | MouserCode | PartNumber
 |  |  | DUPPA_TOP_600x134
Capacitor | C1 | 4u7 | C0603 | 963-EMK107ABJ475MA-T | CC0603KRX5R7BB475
Capacitor | C2 | 100n | C0402 | 603-CC402KRX5R8BB104 | GRM155R61C104KA88D
Capacitor | C3 | 47n | C0402 | 81-GCM155R71E473KA5D | GCM155R71E473KA55D
Capacitor | C4 | 47n | C0402 | 81-GCM155R71E473KA5D | GCM155R71E473KA55D
XH 2.5 Horizontal Male Connector SMD Socket 2.54mm Plug XH Pitch | CON1 |  | S5B-XH-SM4-TB-V |  | S5B-XH-SM4-TB
 | D1 |  | LED-RGB-CA-5mm-SMD
Hole 2mm | Ho1 |  | Hole_2mm
Hole 2mm | Ho2 |  | Hole_2mm
Ferrite Bead | L1 | 600R@100MHz | L0402 | 963-BK1005HS601-T | BK1005HS601-T
Resistor | R1 | 47r | R0402 | 603-RC0402FR-0747RL | RC0402FR-0747RL
Resistor | R2 | 47r | R0402 | 603-RC0402FR-0747RL | RC0402FR-0747RL
Resistor | R3 | 47r | R0402 | 603-RC0402FR-0747RL | RC0402FR-0747RL
Resistor | R4 | 10k | R0402 | 603-RC0402FR-0710KL | RC0402FR-0710KL
Resistor | R5 | 10k | R0402 | 603-RC0402FR-0710KL | RC0402FR-0710KL
Resistor | R6 | 10k | R0402 | 603-RC0402FR-0710KL | RC0402FR-0710KL
Resistor | R7 | 10k | R0402 | 603-RC0402FR-0710KL | RC0402FR-0710KL
 | R8 | 4k7 | R0402 | 603-RC0402FR-074K7L | RC0402FR-074K7L
 | R9 | 4k7 | R0402 | 603-RC0402FR-074K7L | RC0402FR-074K7L
 | SJ5 |  | SJ_2
7 Function Tact and Scroll Wheel | SW1 |  | TSWB-3N |  | TSWB-3N-CB222 LFS
8-bit Microcontrollers - MCU 8-BIT MCU 14KB Flash 1KB RAM, 256 EEPROM | U1 |  | MCHP-QFN-ML20_L | 579-PIC16F18345-I/GZ | PIC16F18345-I/GZ

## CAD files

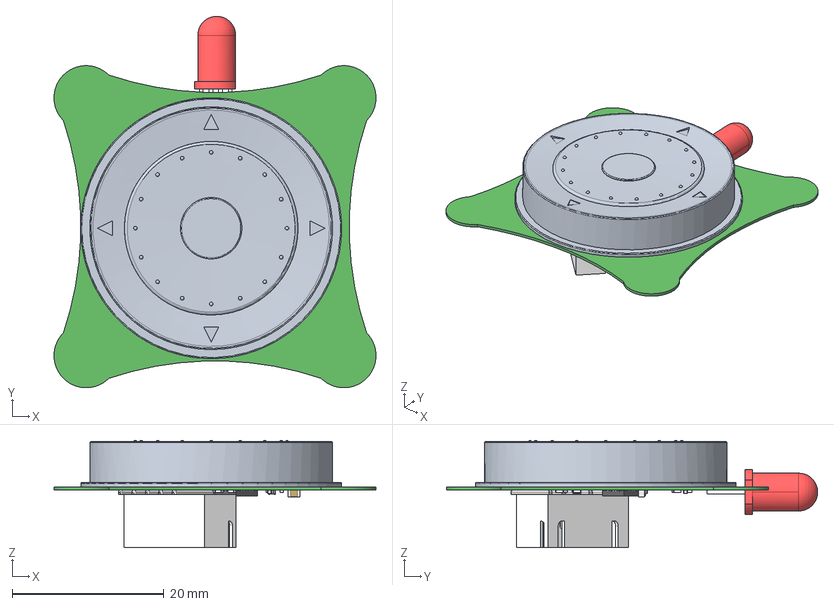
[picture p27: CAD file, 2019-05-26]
Hardware/STEP/I2CNavKey.step
42.5 x 49.0 x 14.2 mm
User_Library-LED_RGB
User_Library-R_0402 x 9
User_Library-QFN20_4x4x0_8
User_Library-V0402HD_K_X_F6rper_1
User_Library-V0402HD_Anschl_X_FCsse_1
User_Library-JST-XH-2_5mm-5
User_Library-Capacitor_0402 x 3
User_Library-CAPC1608X09

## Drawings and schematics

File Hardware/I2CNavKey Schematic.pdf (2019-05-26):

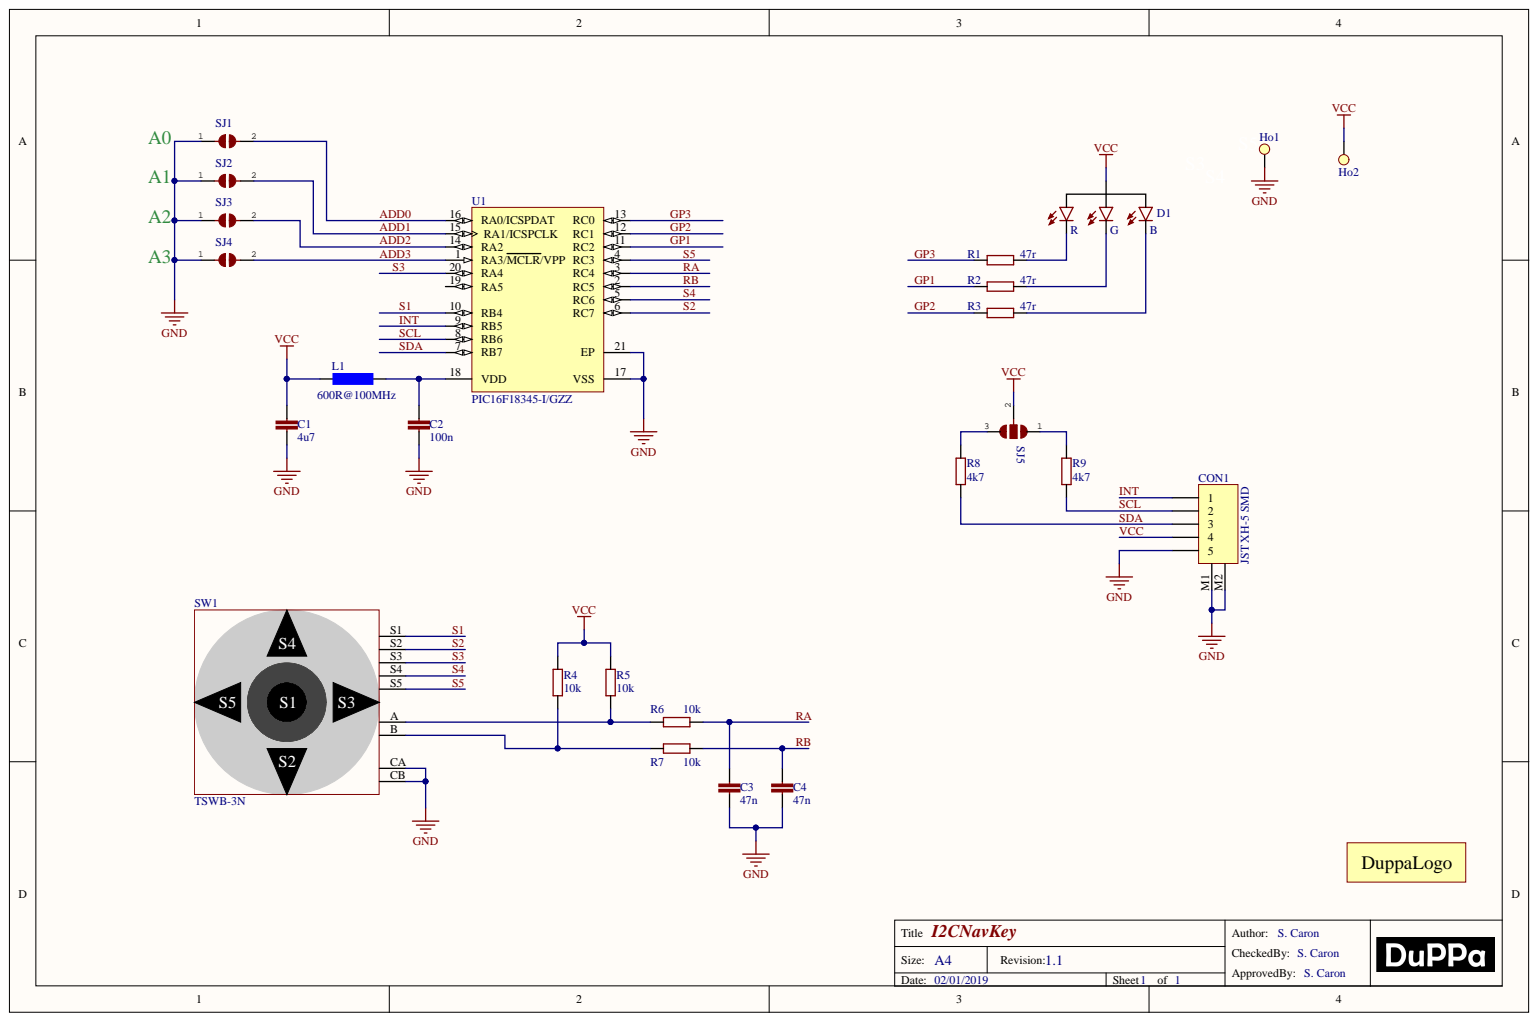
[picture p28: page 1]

I2CNavKey Title | Author: S. Caron CheckedBy: S. Caron ApprovedBy: S. Caron

Size: A4 | Revision: 1.1
Date: 02/01/2019 | Sheet 1 of 1

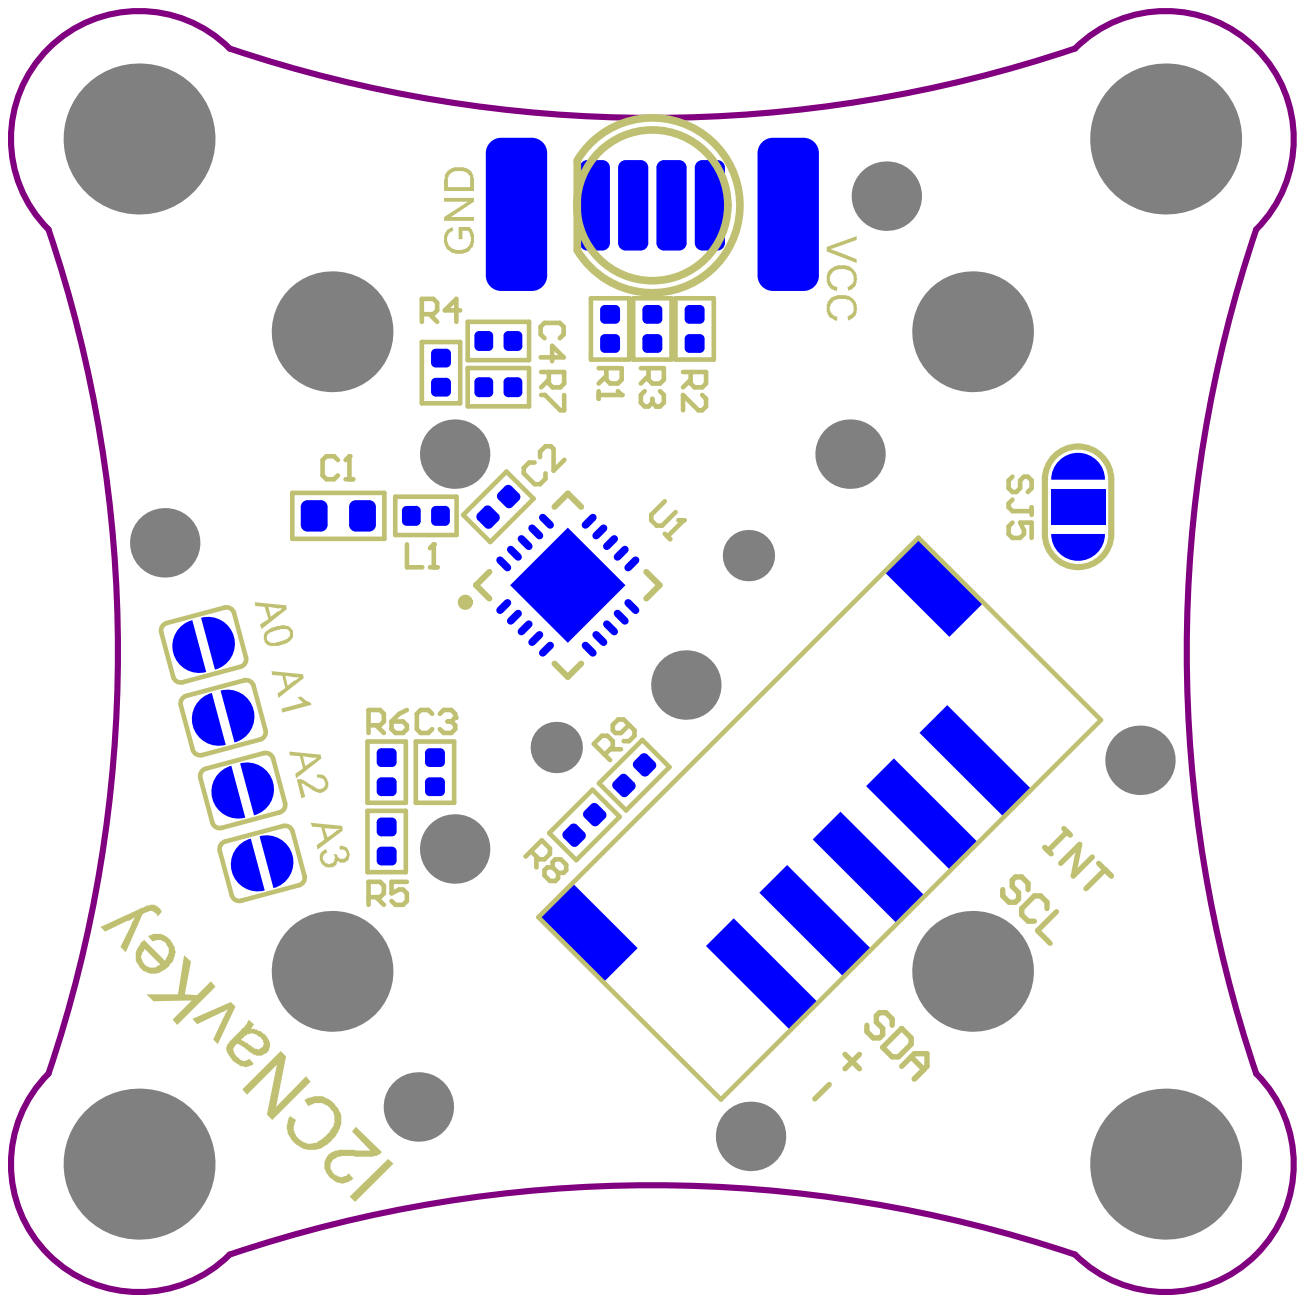
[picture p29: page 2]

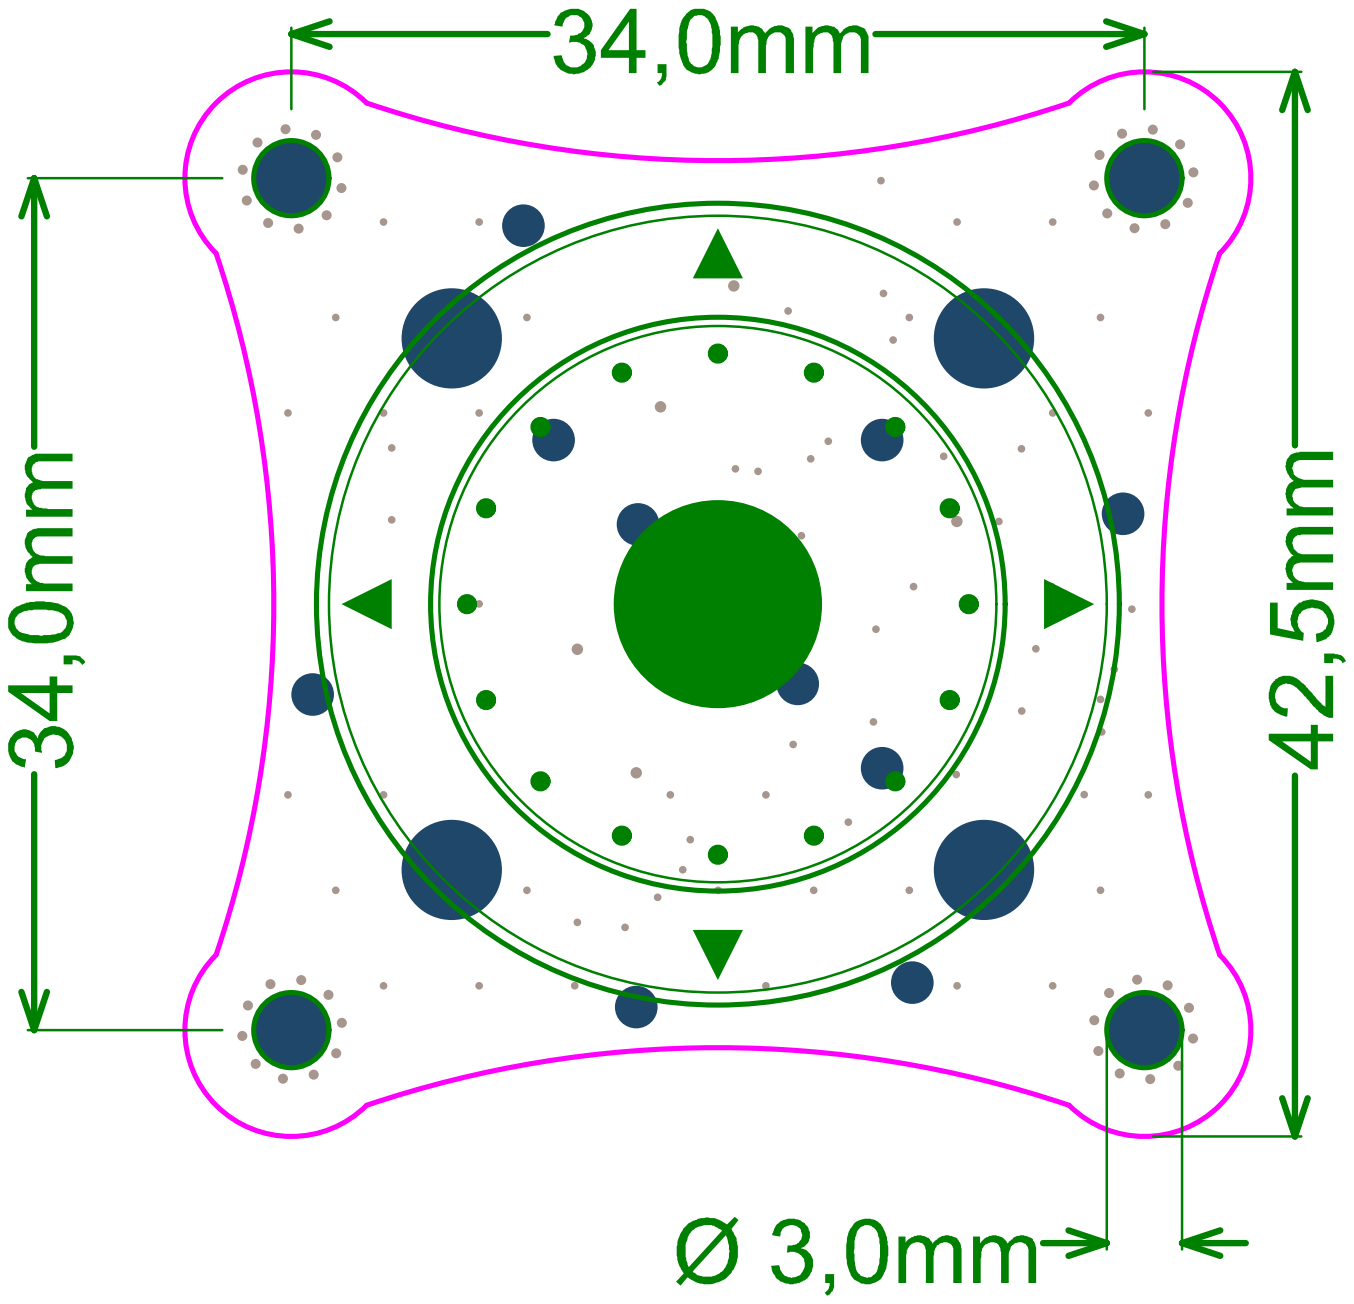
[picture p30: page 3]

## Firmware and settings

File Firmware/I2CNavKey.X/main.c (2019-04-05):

/**
  Generated Main Source File

  Company:
    Microchip Technology Inc.

  File Name:
    main.c

  Summary:
    This is the main file generated using PIC10 / PIC12 / PIC16 / PIC18 MCUs

  Description:
    This header file provides implementations for driver APIs for all modules selected in the GUI.
    Generation Information :
        Product Revision  :  PIC10 / PIC12 / PIC16 / PIC18 MCUs - 1.65.2
        Device            :  PIC16F18344
        Driver Version    :  2.00
 */

/*
    (c) 2018 Microchip Technology Inc. and its subsidiaries. 
    
    Subject to your compliance with these terms, you may use Microchip software and any 
    derivatives exclusively with Microchip products. It is your responsibility to comply with third party 
    license terms applicable to your use of third party software (including open source software) that 
    may accompany Microchip software.
    
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
    IN NO EVENT WILL MICROCHIP BE LIABLE FOR ANY INDIRECT, SPECIAL, PUNITIVE, 
    INCIDENTAL OR CONSEQUENTIAL LOSS, DAMAGE, COST OR EXPENSE OF ANY KIND 
    WHATSOEVER RELATED TO THE SOFTWARE, HOWEVER CAUSED, EVEN IF MICROCHIP 
    HAS BEEN ADVISED OF THE POSSIBILITY OR THE DAMAGES ARE FORESEEABLE. TO 
    THE FULLEST EXTENT ALLOWED BY LAW, MICROCHIP'S TOTAL LIABILITY ON ALL 
    CLAIMS IN ANY WAY RELATED TO THIS SOFTWARE WILL NOT EXCEED THE AMOUNT 
    OF FEES, IF ANY, THAT YOU HAVE PAID DIRECTLY TO MICROCHIP FOR THIS 
    SOFTWARE.
 */

#include "mcc_generated_files/mcc.h"
#include "i2c_register.h"
#include "main.h"
#include "GPports.h"
#include "DataVariable.h"
#include "NavKey.h"

bool fsm_tmr = false;

/**
 * @brief Function for set the output interrupt pin
 */
void SetInterrupt(void) {

    if ((NSTATUS.val & INTCONF.val) != 0) {
        INT_SetLow();
    }
}

/**
 * @brief Function for clear the output interrupt pin
 */
void ClearInterrupt(void) {
    INT_SetHigh();
}

/**
 * @brief Timer 3 interrupt, it's called every 1ms
 */
void TimerInt(void) {
    fsm_tmr = true;
}

/*
                         Main application
 */
void main(void) {
    // initialize the device
    SYSTEM_Initialize();

    // When using interrupts, you need to set the Global and Peripheral Interrupt Enable bits
    // Use the following macros to:

    // Enable the Global Interrupts
    INTERRUPT_GlobalInterruptEnable();

    // Enable the Peripheral Interrupts
    INTERRUPT_PeripheralInterruptEnable();

    // Disable the Global Interrupts
    //INTERRUPT_GlobalInterruptDisable();

    // Disable the Peripheral Interrupts
    //INTERRUPT_PeripheralInterruptDisable();

    TMR3_SetInterruptHandler(TimerInt);
    DataInitSet();
    GP1_SetDigitalInput();
    GP2_SetDigitalInput();
    GP3_SetDigitalInput();

    TMR3_StartTimer();
    ClearInterrupt();

    while (1) {
        if (fsm_tmr == true) {

            fsm_tmr = false;
            NavKey_FSM();
            GP_Ports_FSM();

        }
    }
}
/**
 End of File
 */

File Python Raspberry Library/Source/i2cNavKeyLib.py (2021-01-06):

import smbus
import time
import struct
from time import sleep

# Encoder register definition#
REG_GCONF = 0x00
REG_GP1CONF = 0x01
REG_GP2CONF = 0x02
REG_GP3CONF = 0x03
REG_INTCONFB2 = 0x04
REG_INTCONFB1 = 0x05
REG_STATUSB2 = 0x06
REG_STATUSB1 = 0x07
REG_SSTATUS = 0x08
REG_FSTATUS = 0x09
REG_CVALB4 = 0x0A
REG_CVALB3 = 0x0B
REG_CVALB2 = 0x0C
REG_CVALB1 = 0x0D
REG_CMAXB4 = 0x0E
REG_CMAXB3 = 0x0F
REG_CMAXB2 = 0x10
REG_CMAXB1 = 0x11
REG_CMINB4 = 0x12
REG_CMINB3 = 0x13
REG_CMINB2 = 0x14
REG_CMINB1 = 0x15
REG_ISTEPB4 = 0x16
REG_ISTEPB3 = 0x17
REG_ISTEPB2 = 0x18
REG_ISTEPB1 = 0x19
REG_GP1REG = 0x1A
REG_GP2REG = 0x1B
REG_GP3REG = 0x1C
REG_DPPERIOD = 0x1D
REG_FADEGP = 0x1E
REG_GAMMAGP1 = 0x1F
REG_GAMMAGP2 = 0x20
REG_GAMMAGP3 = 0x21
REG_IDCODE = 0x70
REG_VERSION = 0x71
REG_EEPROMS = 0x80

# Encoder configuration bit. Use with GCONF #
FLOAT_DATA = 0x01
INT_DATA = 0x00
WRAP_ENABLE = 0x02
WRAP_DISABLE = 0x00
DIRE_LEFT = 0x04
DIRE_RIGHT = 0x00
IPUP_DISABLE = 0x08
IPUP_ENABLE = 0x00
CLK_STRECH_ENABLE = 0x10
CLK_STRECH_DISABLE = 0x00
EEPROM_BANK1 = 0x20
EEPROM_BANK2 = 0x00
RESET = 0x80

# Encoder status bits and setting. Use with: INTCONF for set and with ESTATUS for read the bits  #
UPR = 0x0001
UPP = 0x0002
DNR = 0x0004
DNP = 0x0008
RTR = 0x0010
RTP = 0x0020
LTR = 0x0040
LTP = 0x0080
CTRR = 0x0100
CTRP = 0x0200
CTRDP = 0x0400
RINC = 0x0800
RDEC = 0x1000
RMAX = 0x2000
RMIN = 0x4000
INT_2 = 0x8000

# Encoder Int2 bits. Use to read the bits of I2STATUS  #
GP1_POS = 0x01
GP1_NEG = 0x02
GP2_POS = 0x04
GP2_NEG = 0x08
GP3_POS = 0x10
GP3_NEG = 0x20
FADE_INT = 0x40

# Encoder Fade status bits. Use to read the bits of FSTATUS  #
FADE_GP1 = 0x01
FADE_GP2 = 0x02
FADE_GP3 = 0x04

# GPIO Configuration. USe with GP1CONF,GP2CONF,GP3CONF #
GP_PWM = 0x00
GP_OUT = 0x01
GP_AN = 0x02
GP_IN = 0x03

GP_PULL_EN = 0x04
GP_PULL_DI = 0x00

GP_INT_DI = 0x00
GP_INT_PE = 0x08
GP_INT_NE = 0x10
GP_INT_BE = 0x18

# Gamma configuration #

GAMMA_1 = 0
GAMMA_1_8 = 1
GAMMA_2 = 2
GAMMA_2_2 = 3
GAMMA_2_4 = 4
GAMMA_2_6 = 5
GAMMA_2_8 = 6


class i2cNavKeyLib:

    # Event #
    onArrowsPush = None
    onArrowsRelese = None
    onUpPush = None
    onUpRelease = None
    onDownPush = None
    onDownRelease = None
    onRightPush = None
    onRightRelease = None
    onLeftPush = None
    onLeftRelease = None
    onCentralPush = None
    onCentralRelease = None
    onCentralDoublePush = None
    onIncrement = None
    onDecrement = None
    onChange = None
    onMax = None
    onMin = None
    onMinMax = None
    onGP1Rise = None
    onGP1Fall = None
    onGP2Rise = None
    onGP2Fall = None
    onGP3Rise = None
    onGP3Fall = None
    onFadeProcess = None

    stat = 0
    stat2 = 0
    gconf = 0

# Class constructor 

    def __init__(self, bus, add):
        self.i2cbus = bus
        self.i2cadd = add

# Used for initialize the NavKey
    def begin(self, conf):
        self.writeNavKey8(REG_GCONF, conf & 0xFF)
        self.gconf = conf

    def reset(self) :
        self.writeNavKey8(REG_GCONF, 0x80)
        sleep(0.001)

# Call the attached callback if it is defined #
    def eventCaller(self, event) :
        if event:
            event()

# Return true if the status of the NavKey changed, otherwise return false #
# Call also the related callback if defined #
    def updateStatus(self) :
        self.stat = self.readNavKey16(REG_STATUSB2)
        
        if (self.stat == 0):
            self.stat2 = 0
            return False

        if (self.stat & UPR) != 0 :
            self.eventCaller (self.onUpRelease)
            self.eventCaller (self.onArrowsRelese)

        if (self.stat & UPP) != 0 :
            self.eventCaller (self.onUpPush)
            self.eventCaller (self.onArrowsRelese)

        if (self.stat & DNR) != 0 :
            self.eventCaller (self.onDownRelease)
            self.eventCaller (self.onArrowsRelese)
            
        if (self.stat & DNP) != 0 :
            self.eventCaller (self.onDownPush)
            self.eventCaller (self.onArrowsRelese)
            
        if (self.stat & RTR) != 0 :
            self.eventCaller (self.onRightRelease)
            self.eventCaller (self.onArrowsRelese)

        if (self.stat & RTP) != 0 :
            self.eventCaller (self.onRightPush)
            self.eventCaller (self.onArrowsRelese)

        if (self.stat & LTR) != 0 :
            self.eventCaller (self.onLeftRelease)
            self.eventCaller (self.onArrowsRelese)
            
        if (self.stat & LTP) != 0 :
            self.eventCaller (self.onLeftPush)
            self.eventCaller (self.onArrowsRelese)
            
        if (self.stat & CTRR) != 0 :
            self.eventCaller (self.onCentralRelease)

        if (self.stat & CTRP) != 0 :
            self.eventCaller (self.onCentralPush)
            
        if (self.stat & CTRDP) != 0 :
            self.eventCaller (self.onCentralDoublePush)

        if (self.stat & RINC) != 0 :
            self.eventCaller (self.onIncrement)
            self.eventCaller (self.onChange)

        if (self.stat & RDEC) != 0 :
            self.eventCaller (self.onDecrement)
            self.eventCaller (self.onChange)

        if (self.stat & RMAX) != 0 :
            self.eventCaller (self.onMax)
            self.eventCaller (self.onMinMax)

        if (self.stat & RMIN) != 0 :
            self.eventCaller (self.onMin)
            self.eventCaller (self.onMinMax)


        if (self.stat & INT_2) != 0 :
            self.stat2 = self.readNavKey8(REG_SSTATUS)
            if (self.stat2 == 0) :
                return True

            if (self.stat2 & GP1_POS) != 0 :
                self.eventCaller (self.onGP1Rise)

            if (self.stat2 & GP1_NEG) != 0 :
                self.eventCaller (self.onGP1Fall)

            if (self.stat2 & GP2_POS) != 0 :
                self.eventCaller (self.onGP2Rise)

            if (self.stat2 & GP2_NEG) != 0 :
                self.eventCaller (self.onGP2Fall)

            if (self.stat2 & GP3_POS) != 0 :
                self.eventCaller (self.onGP3Rise)

            if (self.stat2 & GP3_NEG) != 0 :
                self.eventCaller (self.onGP3Fall)

            if (self.stat2 & FADE_INT) != 0 :
                self.eventCaller (self.onFadeProcess)
        return True

#********************************* Read functions ***********************************#

# Return the GP1 Configuration#
    def readGP1conf(self) :
        return (self.readNavKey8(REG_GP1CONF))

# Return the GP1 Configuration#
    def readGP2conf(self) :
        return (self.readNavKey8(REG_GP2CONF))

# Return the GP1 Configuration#
    def readGP3conf(self) :
        return (self.readNavKey8(REG_GP3CONF))

# Return the INT pin configuration#
    def readInterruptConfig(self) :
        return (self.readNavKey16(REG_INTCONFB2))
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
